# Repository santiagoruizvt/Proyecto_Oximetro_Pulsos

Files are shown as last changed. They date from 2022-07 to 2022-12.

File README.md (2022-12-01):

# **Proyecto_Oximetro_Pulsos**
*Repositorio destinado para el proyecto de la materia Técnicas Digitales 3*

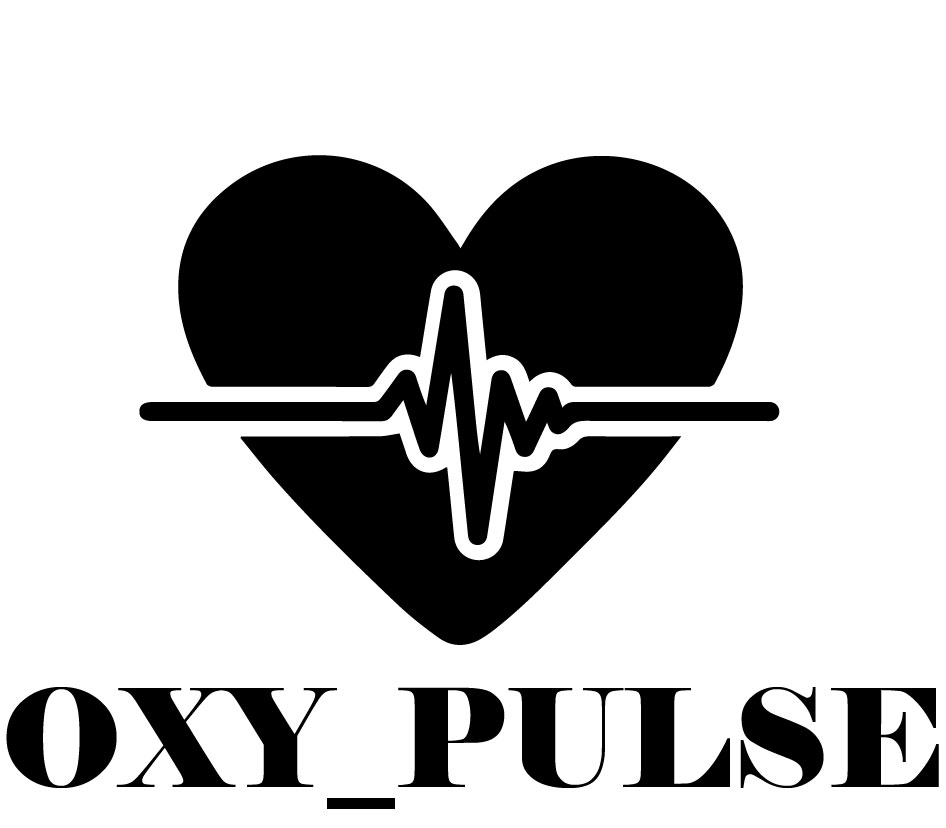
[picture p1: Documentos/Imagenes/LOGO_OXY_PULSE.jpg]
Image text


## Se encuentra disponible en la carpeta "Documentos" el preinforme del proyecto.
## Se encuentra disponible en la carpeta "Documentos" el informe final del proyecto.
## Se agrega el código desarrollado con STM32CubeIDE, con las siguientes configuraciones:

- UART: Se utilizará para la comunicación con el módulo bluetooth HM10.
	- PA2: TX
	- PA3: RX

- SPI: Se utilizará para la comunicación con el módulo R/W de tarjetas Micro SD
	- PB12: CSS
	- PB13: SCK
	- PB14: MISO
	- PB15: MOSI

- I2C1: Se utilizará para la comunicación con el módulo oxímetro MAX30100
	- PB6: SCL
	- PB7: SDA

- I2C2: Se utilizará para la comunicación con la pantalla OLED SSD1306
	- PB10: SCL
	- PB11: SDA

- PULSADOR: Se utilizará para comenzar con la medición.
	- PC14: PULL-UP

# Modelos 3D

## Diseños realizados con Fusion 360 (Autodesk)

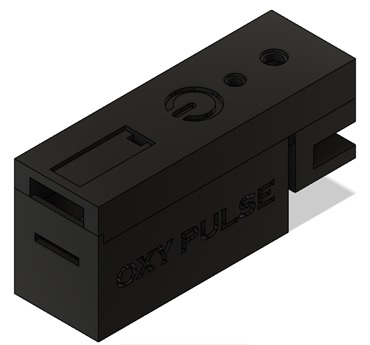
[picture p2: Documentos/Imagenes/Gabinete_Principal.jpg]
Image text


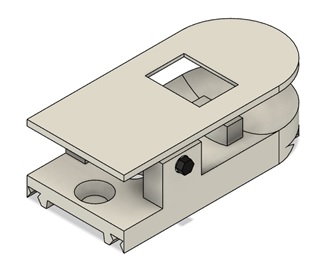
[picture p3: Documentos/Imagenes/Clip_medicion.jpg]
Image text


# PROYECTO FINALIZADO

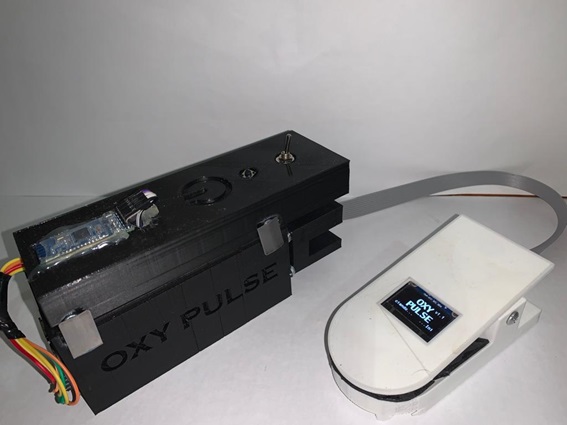
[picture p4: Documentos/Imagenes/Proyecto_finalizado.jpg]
Image text


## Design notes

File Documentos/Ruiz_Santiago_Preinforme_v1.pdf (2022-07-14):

## Oxy_Pulse

Alumno:

- Ruiz Santiago

Descripción funcional del proyecto:

“Oxy_Pulse” es un oxímetro de pulsos y medidor de frecuencia cardíaca, diseñado para ser un dispositivo portátil y de fácil manejo para el usuario.
Es importante conocer los niveles de oxígeno en sangre, ya que si este es bajo las células del organismo pueden tener dificultades para cumplir adecuadamente sus funciones. El oxígeno es el “combustible” del cuerpo y cuando el 02 falta el cuerpo no funciona bien. Los bajos niveles de oxígeno también pueden repercutir sobre el corazón y el cerebro.
Este dispositivo mide los niveles de oxígeno en sangre sin necesidad de entrar en contacto con la misma y los presenta en pantalla para su lectura. El nivel de oxígeno en sangre obtenido se denomina “nivel de saturación de oxígeno” e indica cuánto oxígeno transporta la sangre en relación al máximo que sería capaz de transportar. En circunstancias normales, más del 89% de los glóbulos rojos debería contener oxígeno.
El dispositivo además indica la frecuencia cardíaca del usuario, y envía alertas por bradicardia o taquicardia vía Bluetooth a una aplicación móvil sencilla que el usuario puede descargar en su teléfono.
Por otra parte, cuenta con un módulo para tarjetas SD, donde se irán almacenando datos de lecturas que el usuario luego podrá utilizar a la hora de elaborar un informe médico.

Descripción técnica del proyecto:

- Entradas y salidas del sistema
- Entradas: Sensor MAX30102 y pulsador de PULL-UP.
- Salidas: Módulo Bluetooth HM10, Módulo SD Card R/W, Pantalla OLED SSD1306, leds indicadores.
- Sensores a utilizar
- Sensor oxímetro de pulsos y medidor de frecuencia cardíaca MAX30102 o MAX30100
- Circuitos integrados incluidos en el sistema
- Módulo HM10 para la conexión bluetooth del dispositivo.
- Pantalla OLED SSD1306.
- Módulo SD Card (OKY 3001) o Micro SD
- Tipo de alimentación: el dispositivo contará con baterías de litio tipo 18650 con posibilidad de recargarlas utilizando un módulo de carga TP4056.
- Comunicaciones a efectuar con los distintos módulos:
- I2C1: se utilizará para comunicar el STM32F103 con el módulo oxímetro, utilizando los pines PB7(SDA1) y PB6(SCL1).

- I2C2: se utilizará para comunicar el STM32F103 con la pantalla OLED, utilizando los pines PB11(SDA2) y PB10(SCL2)
- UART: se utilizará para comunicar el STM32F103 con el módulo bluetooth HM10, utilizando los pines PA2(TX2) y PA3(RX2)
- SPI: se utilizará para comunicar el STMF103 con el módulo de
tarjeta | SD, | utilizando | los | pines | PB12(CS), | PB13(CLK),
PB14(MISO), PB15(MOSI).

Planificación de ejecución:

- Tareas necesarias a llevar a cabo para desarrollar el proyecto:
- Testeos de los componentes:
- Prueba de módulo bluetooth HM10: Se realizará una prueba enviando un carácter vía bluetooth para encender y apagar un led.
- Prueba de pantalla OLED SSD1306: Se buscará escribir en pantalla alguna frase e ir mostrando el cambio de alguna variable. Como segunda prueba, se buscará graficar algún símbolo o imagen relacionada con la funcionalidad del proyecto (señal ECG de referencia o un corazón latiendo)
- Prueba del módulo R/W de Tarjetas SD(o Micro SD): Se realizará el conexionado y se buscará escribir la memoria SD, para luego hacer una lectura de esta información en la PC.
- Prueba del módulo MAX30100(o 30102): Se realizará una prueba de la recepción de datos vía I2C para luego procesarlos con el STM32F103.
- Diseño e impresión en 3D de las partes mecánicas del proyecto.
- Redacción de programas para cada módulo

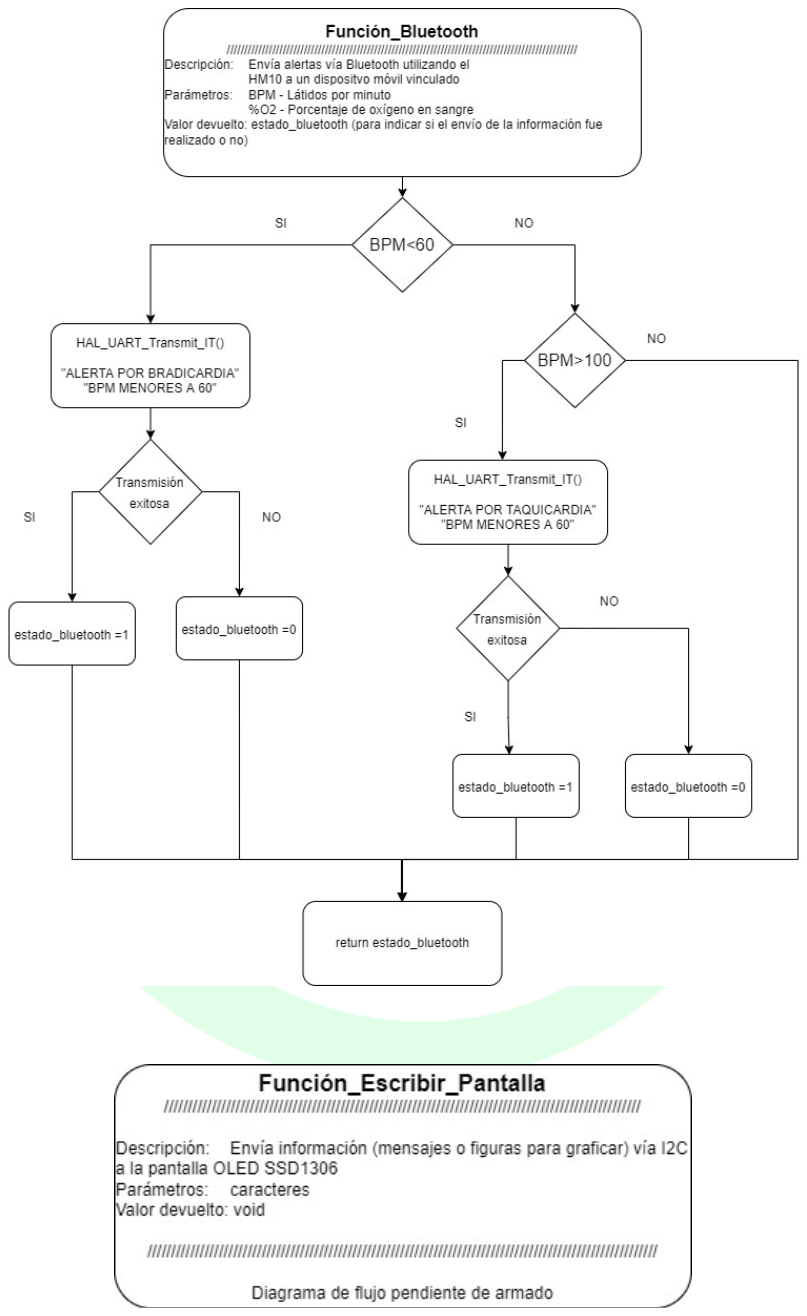
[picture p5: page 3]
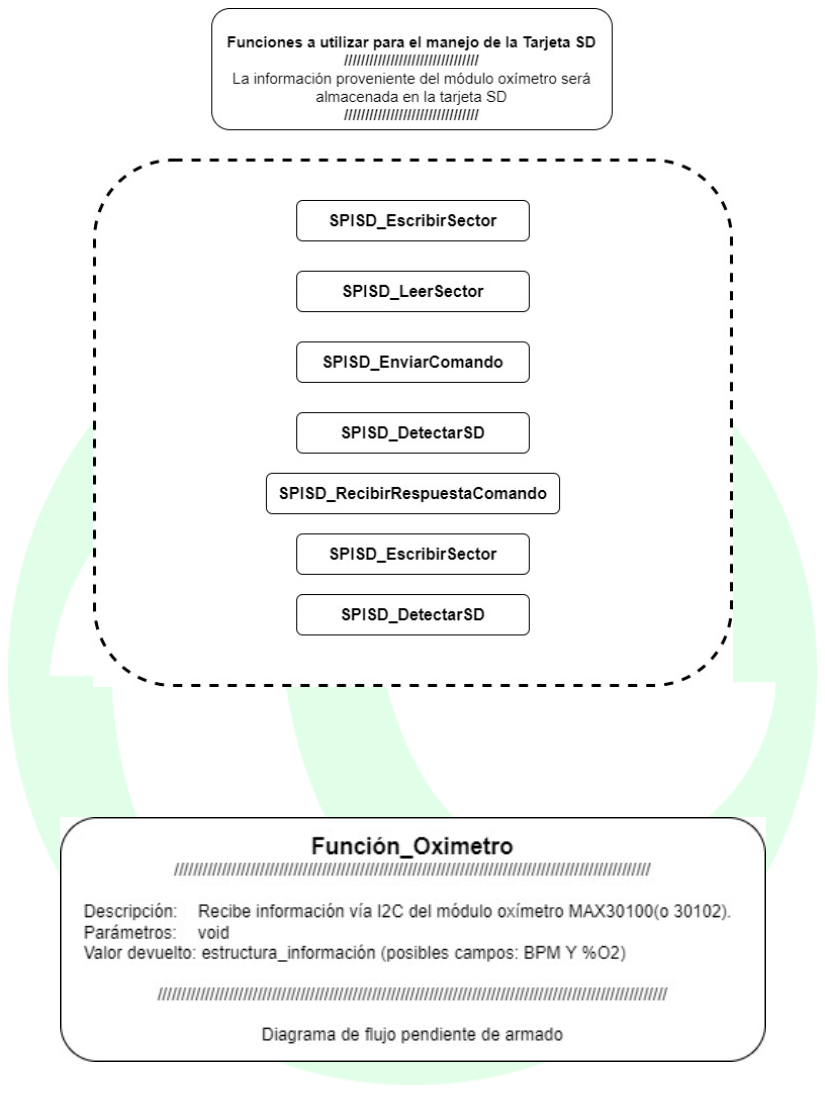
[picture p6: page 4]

- Diseño del programa del sistema

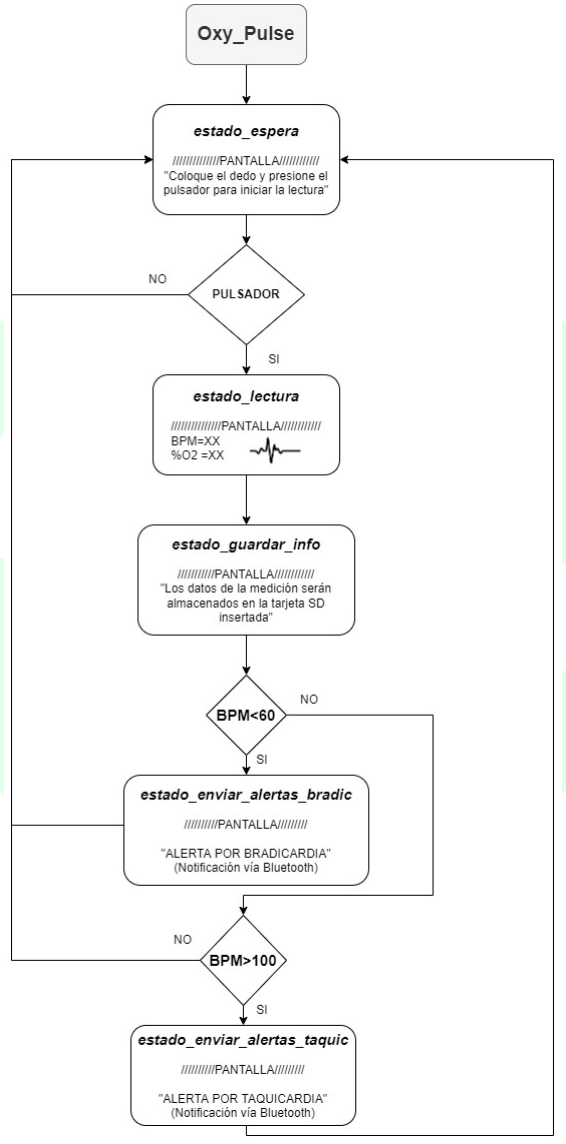
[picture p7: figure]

- Diseño y armado de PCBs: el PCB será incluido en esta sección y será en función del siguiente circuito esquemático:

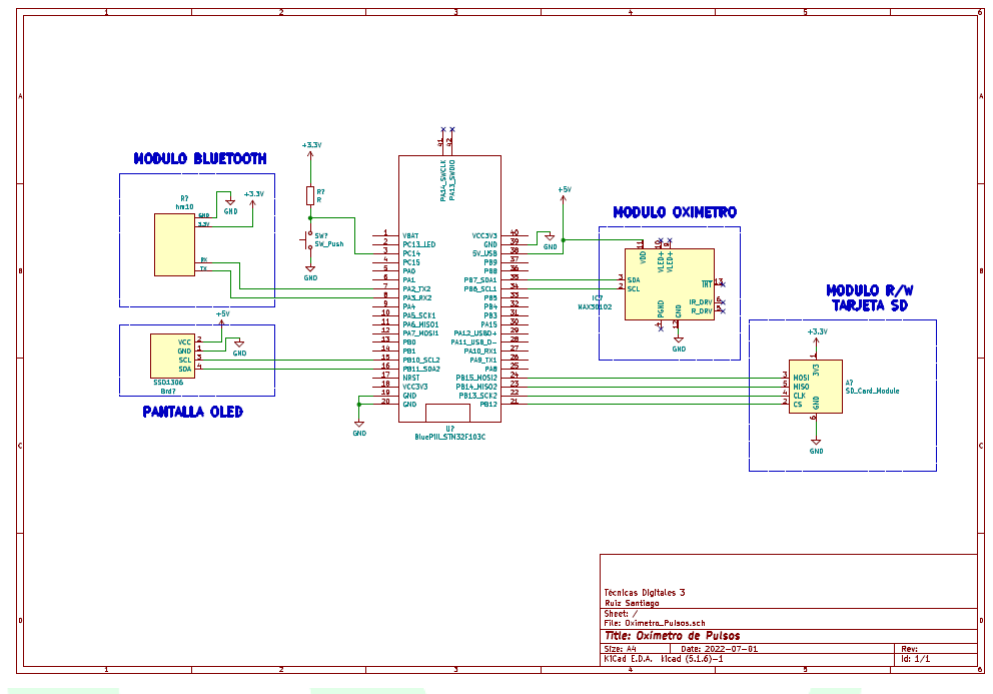
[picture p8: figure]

- Orden de las tareas:
1. Diseño del circuito esquemático
2. Prueba de módulo Bluetooth HM10
3. Prueba de pantalla OLED SSD1306
4. Prueba de módulo de Tarjeta SD
5. Prueba de módulo oxímetro MAX30100/MAX30102
6. Diseño e impresión en 3D de las partes mecánicas
7. Diseño y procesado del PCB
8. Armado y prueba del funcionamiento en conjunto

- Tiempo estimado para cada tarea:
TAREA A REALIZAR | ABRIL | MAYO | JUNIO | JULIO | AGOSTO | SEPTIEMBRE | OCTUBRE | NOVIEMBRE
Propuestas de Proyectos y Elección del definitivo

Elección de sensores y módulos a utilizar

Diseño de Circuito Esquemático

Prueba de módulo Bluetooth

Prueba de pantalla OLED
Prueba de módulo de Tarjeta SD

Prueba del módulo oxímetro

Diseño e impresión 3D de las partes mecánicas

Diseño y Procesado del PCB

Pruebas en conjunto y coordinación

Programación Principal
Corrección de Errores y Ajustes

Presentación

La extensión mínima del documento entregado deberá ser de tres páginas y se debe respetar el formato de este modelo, no solo en el tipo de letra y la tabulación, sino también en el orden y presencia de los títulos incluidos. Téngase en cuenta que conforme más información (tanto de la parte técnica como de la planificación) se entregue, mas fácil será para la cátedra el acotar los proyectos a los tiempos y conocimientos de los cuales se dispone y más efectivo podrá ser el seguimiento que se hará de los mismos, siendo los alumnos los principales beneficiarios.

Universidad Nacional de La Matanza

Técnicas Digitales III

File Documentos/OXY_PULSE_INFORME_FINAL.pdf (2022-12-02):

## UNIVERSIDAD NACIONAL DE LA MATANZA

## Departamento de Ingeniería e Investigaciones Tecnológicas

## Ingeniería en Electrónica

# Técnicas digitales III

# OXY_PULSE

Alumno: | Santiago Ruiz
Profesores: | Lic. Carlos Maidana
| Ing. Guillermo Buranits
| Ing. Edgardo Alberto Gho

2022

## ÍNDICE

UNLaM | Ingeniería Electrónica | Técnicas digitales III
RUIZ | 1

## 1 Descripción general

El control de la frecuencia cardíaca y del nivel de oxigenación en sangre es un hábito saludable que las personas, incluso si no son atletas, deberían practicar. Esto ayuda a controlar el estado físico e inclusive a detectar problemas de salud. Existen diversas formas de conocer la frecuencia del pulso cardíaco, detectándolo en alguna zona sensible del cuerpo como las muñecas o de lado del cuello. La más conocida consiste en contar los latidos que uno encuentra tocando estas zonas durante 60 segundos.

Como solución tecnológica a esta necesidad, se presenta “OXY_PULSE”. Se trata de un oxímetro de pulsos diseñado para ser portátil y de fácil manejo para el usuario. Con la ayuda de este dispositivo, el usuario podrá realizar una medición de su frecuencia cardíaca y de la saturación de oxígeno en sangre, sin tener que extraer una muestra de sangre. Estos valores podrán leerse en pantalla de forma rápida y en unos pocos segundos, para tener así una noción de sus latidos por minuto y oxigenación. Para le medición, solo se necesita colocar el dedo en el sensor e iniciar la lectura accionando un pulsador.

Adicionalmente, el dispositivo cuenta con conectividad Bluetooth, para poder conectarse y enviar información a un dispositivo móvil. Además, enviará alertas en caso de que las lecturas de frecuencia cardíaca no estén dentro de un rango de valores normales para un adulto.

Existe además la posibilidad de conectar una tarjeta SD, donde se irán guardando valores de latidos por minuto (BPM) o saturación de oxígeno en sangre (SPO2) por cada lectura que se haga, lo cual podría ser de utilidad a la hora de elaborar un informe médico.

En resumen, se desarrolla un dispositivo para utilizar en el hogar, sin tener conocimientos técnicos ni médicos, que pueda entregar al usuario una noción rápida de sus niveles de oxigenación y frecuencia cardíaca de manera sencilla.

Figura 1 - Logotipo OXY_PULSE

## 2 Introducción teórica

El monitoreo de parámetros como la frecuencia cardíaca y la saturación de oxígeno es hoy en día una necesidad a nivel mundial para el cuidado médico de pacientes. Y si se toma en cuenta lo sucedido con la pandemia del COVID-19, el control de estos parámetros se enfatizó debido a las características y consecuencias de la enfermedad. Estos parámetros proporcionan información acerca del paciente, aun cuando este no puede expresarlo por sus propios medios y cualquier desviación de los valores considerados normales de estos signos vitales puede significar un riesgo en la salud del paciente. Se consideran signos vitales al ritmo cardíaco, la presión arterial, la temperatura corporal y la frecuencia respiratoria. Y desde la aparición del primer oxímetro de pulsos en 1975 se considera a la saturación de oxígeno como el quinto signo vital.
Para entender el funcionamiento de un oxímetro, primero es necesario desarrollar algunos conceptos teóricos. La sangre es tejido vivo formado por líquidos y sólidos. La parte líquida, llamada plasma, contiene agua, sales y proteínas. Más de la mitad del cuerpo humano es plasma. Mientras que la parte sólida de la sangre contiene glóbulos rojos, glóbulos blancos y plaquetas. Dentro del plasma, la hemoglobina es la proteína principal que transporta el oxígeno en la sangre, y cambia de color cuando se une al oxígeno. La hemoglobina consiste en proteínas globulares, presentes en los hematíes en altas concentraciones, que fijan oxígeno en los pulmones y lo transportan por la sangre hacia los tejidos y células que rodean el lecho capilar del sistema vascular. Al volver a los pulmones, desde la red de capilares, la hemoglobina actúa como transportador de CO2 y de protones. Considerando este cambio de color mencionado, un oxímetro podrá detectar con el uso de sensores los cambios de color en la sangre debido al movimiento de hemoglobina unida al oxígeno, obteniendo una cantidad porcentual de moléculas de hemoglobina conocida como saturación de oxígeno en sangre (SPO2). En forma resumida, la principal función de la hemoglobina es el transporte de oxígeno (O2) de los pulmones donde la presión es elevada hacia los tejidos donde es baja.

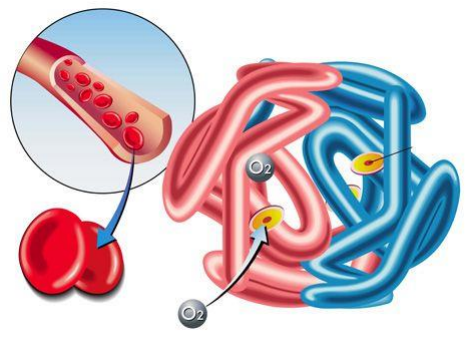
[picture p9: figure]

Figura 2 – Molécula de Hemoglobina

A partir de estos conceptos es que surge la oximetría, definida en términos generales como la medición óptica de la saturación de oxihemoglobina en la sangre. En particular será de interés la oximetría de pulsos.
Un instrumento que sería capaz de detectar los cambios de color mencionados es un espectrofotómetro, el cual tiene la capacidad de detectar con precisión la reflectancia del color o la transmisión de luz para el análisis cuantitativo. Cada muestra física tiene su propia reflectancia (cantidad de luz que refleja) y transmitancia (absorción de luz). Desarrollando un poco más, un espectrofotómetro mide la intensidad de la luz transmitida a través de una sustancia a una determinada longitud de onda. La fracción de luz absorbida a una cierta longitud de onda está dada por la absortividad. El espectrofotómetro posee un fotodetector, el cual convierte la intensidad de luz en corriente eléctrica. A una intensidad de luz dada transmitida a través de una sustancia se produce una corriente eléctrica proporcional a dicha intensidad. Si se mide la intensidad de luz incidente sobre un material (Io) y la intensidad de luz transmitida a través del mismo material (I) se determina la transmitancia, definida por la siguiente ecuación:

T =

I
Io

(1)

Dado que cada molécula absorbe una proporción igual de luz, la absorbancia de la luz a través de la sustancia esta linealmente relacionada con la concentración de la misma. La absorbancia se obtiene a partir de la transmitancia medida según la ecuación 2:

At = − ln(T) = −ln (

I
Io
) | (2)

Un oxímetro de pulsos irradia luz de dos longitudes de onda a través de una capa de tejido y mide la señal de la luz transmitida. El dispositivo apoya su funcionamiento en dos leyes principales, la ley de Lambert y la ley de Beer. La ley de Lambert establece que la potencia de una radiación electromagnética monocromática que incide perpendicularmente en una superficie decrece exponencialmente con el espesor del medio atravesado. La radiación absorbida por el medio se representa con la absorbancia, definida por la ecuación 3, donde b es espesor del medio y k1 una constante de proporcionalidad del medio.

Ai = (

k1
2,3
)b | (3)

Se observa que la absorbancia es directamente proporcional al espesor del medio atravesado. Por otra parte, la Ley de Beer establece que la potencia de una radiación electromagnética monocromática que incide perpendicularmente sobre una muestra decrece exponencialmente con la concentración de la muestra, siguiendo la ecuación 4:

Ab = (

k2
2,3
) c | (4)

Donde c es la concentración de la muestra, k2 una constante de proporcionalidad y Ab la absorbancia.
Combinando las leyes mencionadas anteriormente, se obtiene la Ley de Lambert-Beer que describe la atenuación de la luz que viaja a través de un medio uniforme que contiene una sustancia absorbente. La intensidad I de la luz que viaja a través del medio decrece exponencialmente con las distancias y está definida por la ecuación 5, donde ε(λ) es el coeficiente de extinción de la sustancia absorbente, λ es la longitud de onda, c es la concentración de la sustancia absorbente que es constante en el medio, y d es la longitud del camino óptico a través del medio.

I = Ioe

−ε(λ)cd
(5)

En la Figura 3, se puede observar un diagrama de absorción de un haz que atraviesa un recipiente de tamaño L:

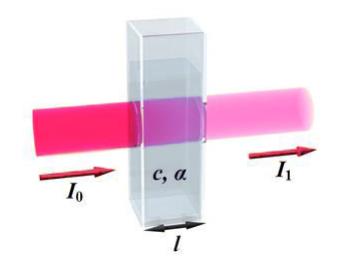
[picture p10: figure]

Figura 3 – Representación de la Ley de Lambert-Beer

Las propiedades de esta ley son válidas incluso si hay más de una sustancia absorbente en el medio. Cada sustancia contribuye con su parte a la absorbancia total dando como resultado que la misma es la suma de las n-ésimas absorbancias presentes en el medio. Volviendo al instrumento de interés para el trabajo, un oxímetro de pulsos irradia luz de dos longitudes de onda a través de una capa de tejido y mide la señal de la luz transmitida.
En primer lugar, el oxímetro mide cuanta cantidad de luz alcanza al fotodetector y en función de esto determina cuanta luz ha sido absorbida. La hemoglobina absorbe luz y la cantidad de luz absorbida es proporcional a la concentración de hemoglobina. Por eso a mayor concentración de hemoglobina en la zona que se está observando, mayor luz será absorbida.

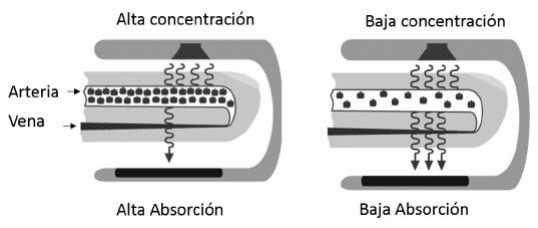
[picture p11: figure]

Figura 4 – Aplicación de la Ley de Beer

En segundo lugar, la cantidad de luz absorbida es proporcional a la longitud del camino de luz. Esto describa una posible situación donde en dos dedos humanos diferentes pueden existir arterias que tienen la misma concentración de hemoglobina por unidad de área, pero estas arterias pueden ser de diferentes espesores. En la de mayor espesor, la luz emitida desde la fuente debe recorrer un camino de mayor longitud que en la arteria más pequeña, aunque la concentración de hemoglobina sea la misma en ambas arterias. En la arteria de mayor espesor, el medio absorbe mayor cantidad de luz.

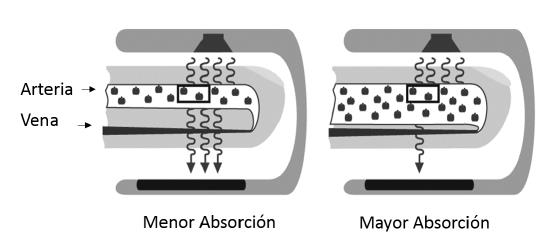
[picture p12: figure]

Figura 5 – Aplicación de la Ley de Lambert

Como última consideración, es importante mencionar que la oxihemoglobina absorbe mayor cantidad de radiación infrarroja y la desoxihemoglobina absorbe mayor cantidad de radiación roja. Es por esto que el oxímetro utiliza dos haces de luz de diferentes longitudes de onda para analizar la hemoglobina: un haz es la luz roja con una longitud de onda de 650nm aproximadamente, mientras que el otro haz es luz infrarroja con una longitud de 950nm. Graficando la absorbancia de la oxihemoglobina y la desoxihemoglobina, se obtiene una gráfica como la de la figura 6:

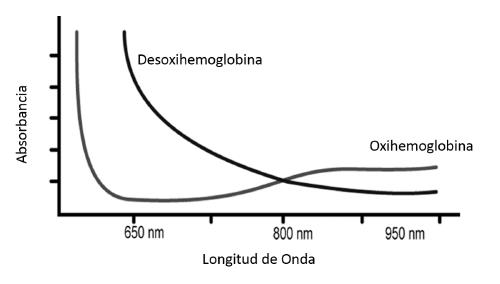
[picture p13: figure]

Figura 6 – Absorbancia en función de la longitud de onda

De la figura 6 se entiende que para valores infrarrojos (950nm) la absorbancia de la oxihemoglobina es mayor que para valores de longitudes de onda menores. De forma similar, pero observando la curva de desoxihemoglobina se observa que absorbe mayor luz de longitud de onda roja (650nm) que infrarroja.
El oxímetro de pulsos opera determinando la saturación de oxígeno al comparar cuanta luz roja e infrarroja es absorbida por la sangre. Dependiendo de las cantidades de oxihemoglobina y desoxihemoglobina, la relación de luz roja absorbida se compara con la relación de luz infrarroja absorbida.
Se define como onda fotopletismográfica al cambio de volumen del flujo sanguíneo. En las extremidades, como un dedo, esta onda se ve afectada por diversos factores como ruido ambiental, anormalidades en la sangre, movimientos no controlados del cuerpo, etc. Y además, no solo está presente la sangre arterial en el dedo, sino que existen sustancias, como los tejidos, que pueden interferir en la medición. La solución para este inconveniente es la detección de una absorbancia pulsante por parte de la sangre arterial, mientras que el resto de los tejidos no cuentan con esta característica. Por ende, cualquier absorbancia variable en el tiempo se debe a sangre arterial. Se puede decir entonces, que la señal que llega al oxímetro de pulsos es una combinación de una absorbancia variante debido a la sangre arterial y una absorbancia constante debida a la piel y otros tejidos, como se aprecia en la figura 7.

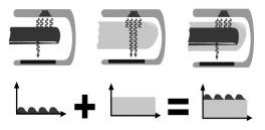
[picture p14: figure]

Figura 7 – Combinación de absorbancias de la sangre y otros tejidos

## 3 Descripción técnica del proyecto

El prototipo consta de dos partes principales. El gabinete principal, donde se aloja el microcontrolador, y un clip externo donde se deberá colocar el dedo para la medición. El diseño de estas piezas fue realizado en el software Autodesk Fusion 360, y las mismas fueron impresas en 3D en PLA.

## 3.1 Mecánica

El prototipo no posee partes móviles exceptuando el clip donde el usuario coloca el dedo. El mismo fue pensado para que, con el uso de un resorte, pueda volver a la posición original luego de ser abierto.

## 3.1.1 Diagrama en bloques

En el siguiente diagrama, se muestran las partes del dispositivo mencionadas anteriormente. La unión entre ellas será un cable plano que conectará el microcontrolador con la pantalla y el módulo oxímetro.

Figura 8 – Diagrama en bloques de la parte mecánica

## 3.1.2 Funcionamiento de cada bloque

El primer bloque es el gabinete principal. Su función es la de la contener la placa principal del prototipo, así como también algunos módulos como el bluetooth o la tarjeta SD. En ella se aloja el microcontrolador. Fue diseñada con el software mencionado anteriormente, y en sus laterales se puede observar el nombre “OXY_PULSE” y un logotipo del producto.
En segundo lugar, se tiene el clip o broche para medición. En él se encuentra una pequeña pantalla OLED, donde el usuario podrá ir leyendo los valores que se están obteniendo, y el módulo oxímetro donde deberá apoyar el dedo a la hora de realizar la medición.

## 3.1.3 Fotos

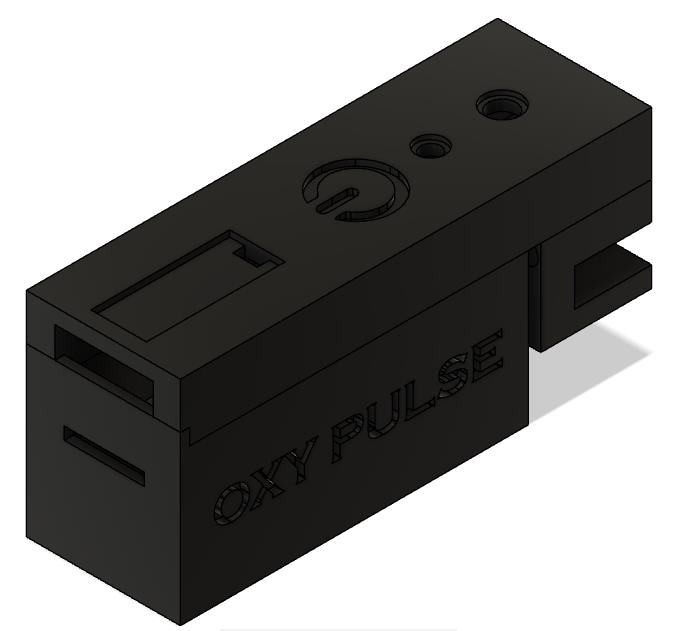
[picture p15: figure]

Figura 9 – Gabinete principal

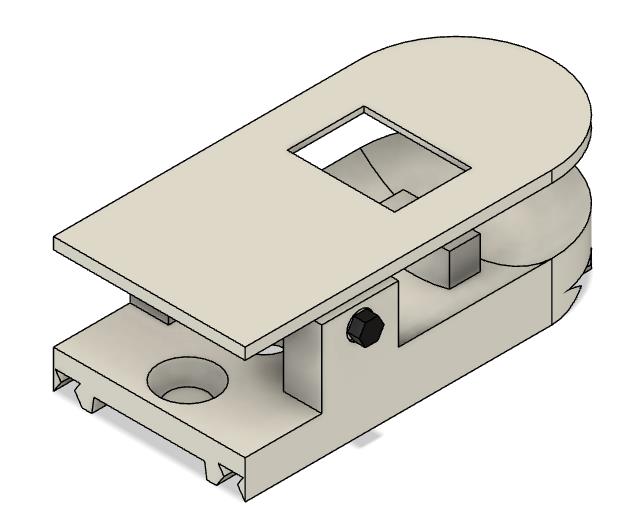
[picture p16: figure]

Figura 10 – Clip para medición

## 3.2 Hardware

En cuanto al hardware, la electrónica del proyecto quedará distribuida en las dos partes mencionadas anteriormente. En el gabinete principal se encontrará la placa con el microcontrolador, el módulo Bluetooth y el módulo para tarjetas SD. Además, se tiene un conector IDC, de donde saldrá la conexión hacia el clip de medición. En este último se encontrará la pantalla OLED y el módulo oxímetro.

## 3.2.1 Diagrama en bloques

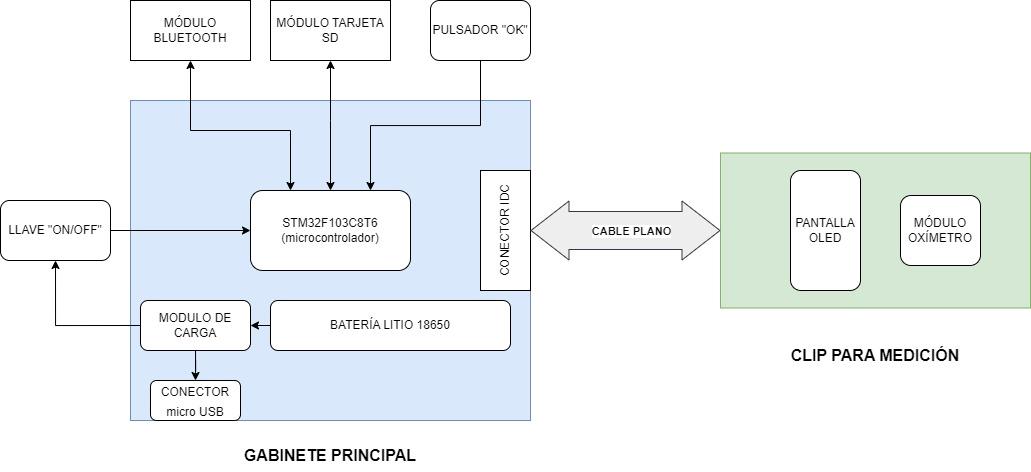
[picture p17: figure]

Figura 11 – Diagrama en bloques de OXY_PULSE

El diagrama presentado se encuentra dividido en dos grandes bloques, los cuales coinciden con las dos partes mecánicas mencionadas en la sección anterior. A continuación, se irán detallando cada una de sus partes.

## 3.2.2 Esquemático

MICROCONTROLADOR – STM32F103C8T6
Se trata de un Cortex M3 de 32 bits, de arquitectura ARM. Permite una frecuencia máxima de operación de 72MHz, con una memoria Flash de 64/128KB, periféricos como I2C, DMA, UART, SPI, CAN, USB, entre otros. Cuenta con 5 timers y 37 pines GPIO. Será el encargado de coordinar las tareas de OXY_PULSE, interactuando con los módulos que se detallarán a continuación.

MÓDULO OXIMETRO
El módulo seleccionado es el MAX30100. Para la selección de este se enfocó la búsqueda en un dispositivo integrado capaz de realizar medición de latidos por minuto y saturación de oxígeno en sangre, tareas principales del dispositivo. El dispositivo consiste en un pulsioxímetro integrado, compuesto por dos LEDS, uno rojo y uno infrarrojo, un fotodetector y un sistema de procesamiento digital de señales para la correcta detección de valores. Sus principales aplicaciones son el uso en accesorios como smartwatch o pulseras de uso deportivo para el monitoreo del pulso cardíaco, y en dispositivos de electromedicina sencillos.
Respecto a la alimentación, el MAX30100 debe ser alimentado desde 1,8V a 3,3v. Pero el módulo utilizado cuenta con un pequeño regulador de 3,3v, por lo que se podría alimentar el módulo con 5V.

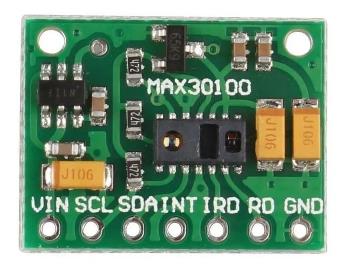
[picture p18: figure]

Figura 12 – MAX30100

Lo interesante de este módulo es que cuenta con interfaz I2C para la comunicación con un microcontrolador. En la hoja de datos del MAX30100, se especifica que para el correcto funcionamiento del bus I2C, se deben colocar resistencias de PULL-UP de 4700Ω.

Figura 13 – BUS I2C MAX30100

En el caso del módulo utilizado, contaba con 3 resistencias de PULL-UP de montaje superficial conectadas de forma errónea, lo cual es un error frecuente en estos módulos. Por este motivo, dichas resistencias fueron quitadas del módulo y colocadas en forma externa en la placa principal.

MÓDULO BLUETOOTH
Para la conectividad Bluetooth, el módulo seleccionado es el HM10. Este módulo cuenta con una versión Bluetooth 4.0 BLE. Las siglas BLE, Bluetooth Low Energy, hacen referencia a una tecnología inalámbrica diseñada para que el consumo de energía sea mucho menor que un bluetooth convencional, aproximadamente un 10% de este. La característica principal es que un dispositivo BLE actúe la mayor parte del tiempo en modo STAND-BY, y sea solo activado para realizar comunicaciones que duran milisegundos. Es por esto, que es una tecnología ideal para dispositivos móviles, smartwatch, etc.
Cuenta con interfaz UART, por lo que con una conexión de 2 hilos (Rx-Tx) de tipo asincrónica puede interactuar con un microcontrolador para transmitir o recibir información.

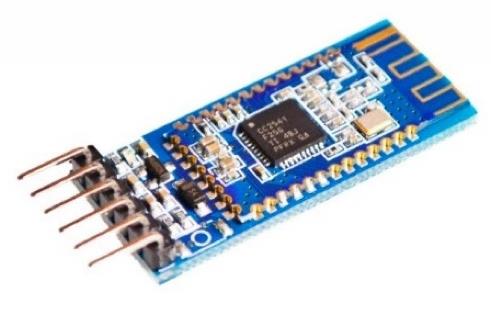
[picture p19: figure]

Figura 14 – BUS I2C MAX30100

PANTALLA OLED
Para la presentación de la información obtenida, se utiliza un módulo Display OLED SSD1306. Posee un panel de 128x64 pixeles y existen versiones multicolor, azules o blancas. Esta última es la utilizada en OXY_PULSE. Cuenta con interfaz I2C para la conexión con un microcontrolador y su alimentación es compatible con lógica de 3,3V.

Figura 15 – Pantalla OLED SSD1306

MODULO TARJETA microSD
Para almacenar información relevante del usuario en una memoria microSD, se utiliza un módulo lector de microSD, para acceder a la memoria en modo SPI. El módulo incluye un “Level-Translator”, para convertir los niveles lógicos de 5v a 3,3V. La comunicación con el microcontrolador es vía SPI, por lo que se tienen 4 hilos (MISO, MOSI, CS, SCK), además de la alimentación.

Figura 16 – Módulo memoria microSD

MODULO DE ALIMENTACIÓN Y CARGA
Para energizar el dispositivo, se utiliza una batería de litio recargable 18650, de la marca UltraFire. La misma proporciona una tensión de 3,7V y una capacidad de 5800mAh. Esta será la encargada de alimentar todos los módulos del dispositivo con lógica de 3,3V. Para la carga de la batería, se utiliza un módulo TP4056 con protección. La ventaja en el uso de este módulo es que cuenta con unos transistores MOSFETs que desconectan la batería del circuito cuando la misma necesita recargarse. Además, posee un conector microUSB para realizar la carga de la batería. Mientras se realiza la carga, el módulo enciende un LED rojo, y cuando la batería llega a plena carga se enciende un LED azul. El diagrama del conexionado es el siguiente:

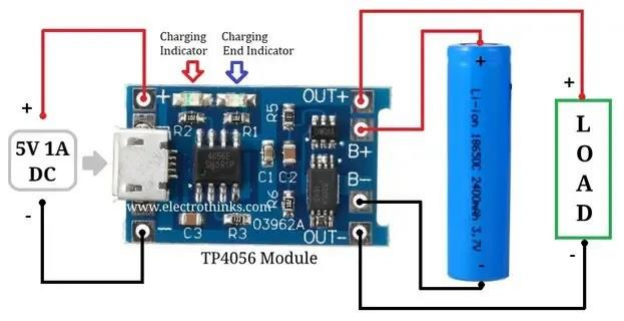
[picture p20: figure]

Figura 17 – Módulo TP4056

LLAVE “ON-OFF” y PULSADOR “OK”
Para el encendido y apagado del dispositivo, se utiliza una mini llave de dos posiciones, que soporta hasta 3A, la cual está en serie con la batería y la bornera principal de la placa.
Por otra parte, el dispositivo cuenta con un pulsador con el cual el usuario podrá iniciar la medición con el oxímetro, así como también detenerla pulsando nuevamente.

CONECTOR IDC
La conexión entre el gabinete principal y el clip para medición es a partir de un conector IDC con latch, el cual permite una conexión hermética sumamente fiable, evitando posibles falsos contactos.

## 3.2.3 Circuito impreso

En el prototipo se cuenta con dos circuitos impresos, diseñados con el software libre KiCad. El primero de ellos y principal, es la placa donde se encuentra el microcontrolador. En ella, se encuentran las conexiones hacia los diferentes módulos mencionados en la sección anterior, así como también resistencias de PULL-UP para los usos ya especificados. El segundo, se trata de una pequeña placa para colocar el conector IDC y darle rigidez mecánica.

## 3.2.4 Fotos

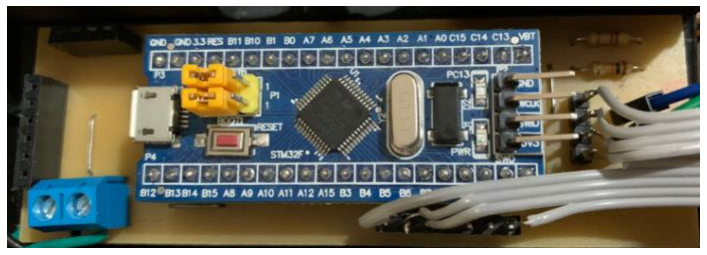
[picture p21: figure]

Figura 18 – PCB principal lado componentes

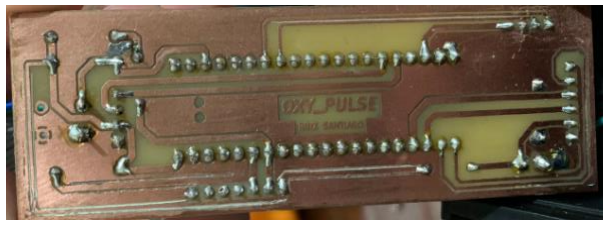
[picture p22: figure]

Figura 19 – PCB principal lado cobre

Figura 20 – PCB para conector IDC

## 3.3 Software

El software de OXY_PULSE fue desarrollado utilizando una herramienta de desarrollo de STMicroelectronics conocida como STM32CubeIDE. Esta basada en el marco Eclipse y la de cadena de herramientas GCC para el desarrollo y GCB para la depuración. Desde el propio entorno, se puede realizar la configuración de la placa de desarrollo utilizando la interfaz del archivo “.ioc”.
El contenido del proyecto fue organizado en archivos, resolviendo cada módulo por separado e incluyendo dichos archivos en el programa principal. Todo el contenido relacionado podrá encontrarse en el repositorio de Github correspondiente a OXY_PULSE. Se puede acceder al mismo siguiendo este link:

https://github.com/santiagoruizvt/Proyecto_Oximetro_Pulsos

## 3.3.1 Enumeración de rutinas

Las rutinas enumeradas a continuación se irán enumerando en grupos según la tarea que cumpla cada una de ellas.

MAX30100.c

Rutina “MAX30100_Init”

//*************************************************************
//Función: | MAX30100_Init
//Descripción: | Inicialización del módulo MAX30100
//Parámetros: | void
//Valor devuelto: | void
//*************************************************************

Subrutina “MAX30100_I2C_Write”

//*************************************************************
//Función: | MAX30100_I2C_Write
//Descripción: | Escritura de un buffer a traves del bus I2C
//Parámetros: | uint8_t dirección del dispositivo
// | uint8_t registro a escribir
// | uint8_t data a escribir
//Valor devuelto: | void
//*************************************************************

Rutina “Actualizar_Resultados”

Subrutina “Resetea_Resultados”

//*************************************************************
//Función: | Resetea_Resultados
//Descripción: | Resetea la estructura result para comenzar
// | o realizar una nueva lectura
//Parámetros: | pulseoxymeter_t* puntero a estructura result
//Valor devuelto: | void
//*************************************************************
Subrutina “Lectura_FIFO”

//*************************************************************
//Función: | Lectura_FIFO
//Descripción: | Lectura de los valores de IR y REDLED desde
// | el registro FIFO del MAX30100
//Parámetros: | FIFO_t* puntero a estructura FIFO
//Valor devuelto: | void
//*************************************************************
Subrutina_2 “MAX30100_I2C_Read”

//*************************************************************
//Función: | MAX30100_I2C_Read
//Descripción: | Lectura de un buffer a traves del bus I2C
//Parámetros: | uint8_t dirección del dispositivo
// | uint8_t registro a escribir
// | uint8_t data a escribir
//Valor devuelto: | void
//*************************************************************

Subrutina “Filtrado_DC”

//*************************************************************
//Función: | Filtrado_DC
//Descripción: | Filtrado para quitar la señal continua
// | presente en los valores leídos
//Parámetros: | float datos del FIFO
// | float* valor previo w
// | float* dato filtrado
//Valor devuelto: | void
//*************************************************************
Subrutina “Filtro de Mediana”

//*************************************************************
//Función: | Mean_Median_Filter
//Descripción: | Filtro de mediana para reducir el ruido y
// | limpiar la señal
//Parámetros: | float datos de la salida del Filtrado_DC
// | meanDiffFilter_t* puntero a estructura
// | float* puntero a dato filtrado resultante
//Valor devuelto: | void
//*************************************************************

Subrutina “Filtro Pasabajos Butterworth”

//*************************************************************
//Función: | Filtro_PasabajosButterworth
//Descripción: | Filtro pasabajos butterworth implementado
// | con una ecuación en diferencia
//Parámetros: | float datos de la salida del Median_Filter
// | butterworthFilter_t* puntero a estructura
// | float* puntero a dato filtrado resultante
//Valor devuelto: | void
//*************************************************************
Subrutina “detectPulse”

//*************************************************************
//Función: | detectPulse
//Descripción: | Máquina de estados para la detección del pulso
//Parámetros: | float datos de la salida del LPF
//Valor devuelto: | bool
//*************************************************************
Subrutina “Balance_Intensidades”

//*************************************************************
//Función: | Balance_Intensidades
//Descripción: | Corrección de las intensidades de los LEDS
// | para evitar la saturación de la lectura
//Parámetros: | float datos del led rojo
// | float datos del led IR
//Valor devuelto: | void
//*************************************************************
Subrutina “MAX30100_I2C_FIFO_Read”

//*************************************************************
//Función: | MAX30100_I2C_FIFO_Read
//Descripción: | Lectura del FIFO del MAX30100, se leen 2 bytes
// | por cada LED
//Parámetros: | void
//Valor devuelto: | void
//*************************************************************
Subrutina “MAX30100_I2C_Reset_FIFO”

//*************************************************************
//Función: | MAX30100_I2C_Reset_FIFO
//Descripción: | Reseteo el registro FIFO
//Parámetros: | void
//Valor devuelto: | void
//*************************************************************

SSD1306.c

Rutina “SSD1306_Init”

//*************************************************************
//Función: | SSD1306_Init
//Descripción: | Incialización de la pantalla OLED
//Parámetros: | void
//Valor devuelto: | uint8_t OK
//*************************************************************
Rutina “SSD1306_GotoXY”

//*************************************************************
//Función: | SSD1306_GotoXY
//Descripción: | Setea las coordenadas XY para escribir
// | en pantalla
//Parámetros: | uint16_t x
// | uint16_t y
//Valor devuelto: | void
//*************************************************************
Rutina “SSD1306_Puts”

//*************************************************************
//Función: | SSD1306_Puts
//Descripción: | Escritura en pantalla carácter por
// | caracter
//Parámetros: | char* string que se desea escribir
// | FontDef_t* tipo de fuente(formato)
// | SSD1306_COLOR_t color de escritura en
// | caso de pantalla multicolor
//Valor devuelto: | char si devuelve “0” OK
//*************************************************************
Rutina “SSD1306_UpdateScreen”

//*************************************************************
//Función: | SSD1306_UpdateScreen
//Descripción: | Actualización de la pantalla con la
// | transmisión por bus I2C de un buffer
// | con la nueva información a mostrar
//Parámetros: | void
//Valor devuelto: | void
//*************************************************************
Rutina “SSD1306_ScrollRight”

//*************************************************************
//Función: | SSD1306_ScrollRight
//Descripción: | Mensaje en movimiento en pantalla
//Parámetros: | uint8_t desde donde arranco
// | uint8_t donde termino
//Valor devuelto: | void
//*************************************************************

Rutina “SSD1306_Stopscroll”

//*************************************************************
//Función: | SSD1306_Stopscroll
//Descripción: | Detiene el movimiento del mensaje
//Parámetros: | void
//Valor devuelto: | void
//*************************************************************
Rutina “SSD1306_Clear”

//*************************************************************
//Función: | SSD1306_Clear
//Descripción: | Limpia la pantalla
//Parámetros: | void
//Valor devuelto: | void
//*************************************************************
Rutina “SSD1306_DrawPixel”

//*************************************************************
//Función: | SSD1306_DrawPixel
//Descripción: | Carga en el buffer la información de que
// | pixel se debe encender y su color
//Parámetros: | uint16_t coordenada X
// | uint16_t coordenada Y
// | SSD1306_COLOR_t color pixel
//Valor devuelto: | void
//*************************************************************
Rutina “SSD1306_DrawBitmap”

//*************************************************************
//Función: | SSD1306_DrawBitmap
//Descripción: | Dibuja en pantalla una imagen mapeada
// | bit a bit
//Parámetros: | uint16_t coordenada X
// | uint16_t coordenada Y
// | const unsigned char* imagen mapeada bit por bit
// | uint16_t ancho de la imagen
// | uint16_t alto de la imagen
// | uint16_t color de cada pixel
//Valor devuelto: | void
//*************************************************************

Main.c

Rutina “HAL_IncTick”

//*************************************************************
//Función: | HAL_IncTick
//Descripción: | Manejo del Systick para demoras en ms
//Parámetros: | void
//Valor devuelto: | void
//*************************************************************

Rutina “HAL_GPIO_EXTI_Callback”

//*************************************************************
//Función: | HAL_GPIO_EXTI_Callback
//Descripción: | Manejo de la interrucpción externa
//Parámetros: | uint16_t GPIO_Pin
//Valor devuelto: | void
//*************************************************************

## 3.3.2 Descripción del funcionamiento de cada rutina

Diagrama de flujo principal:

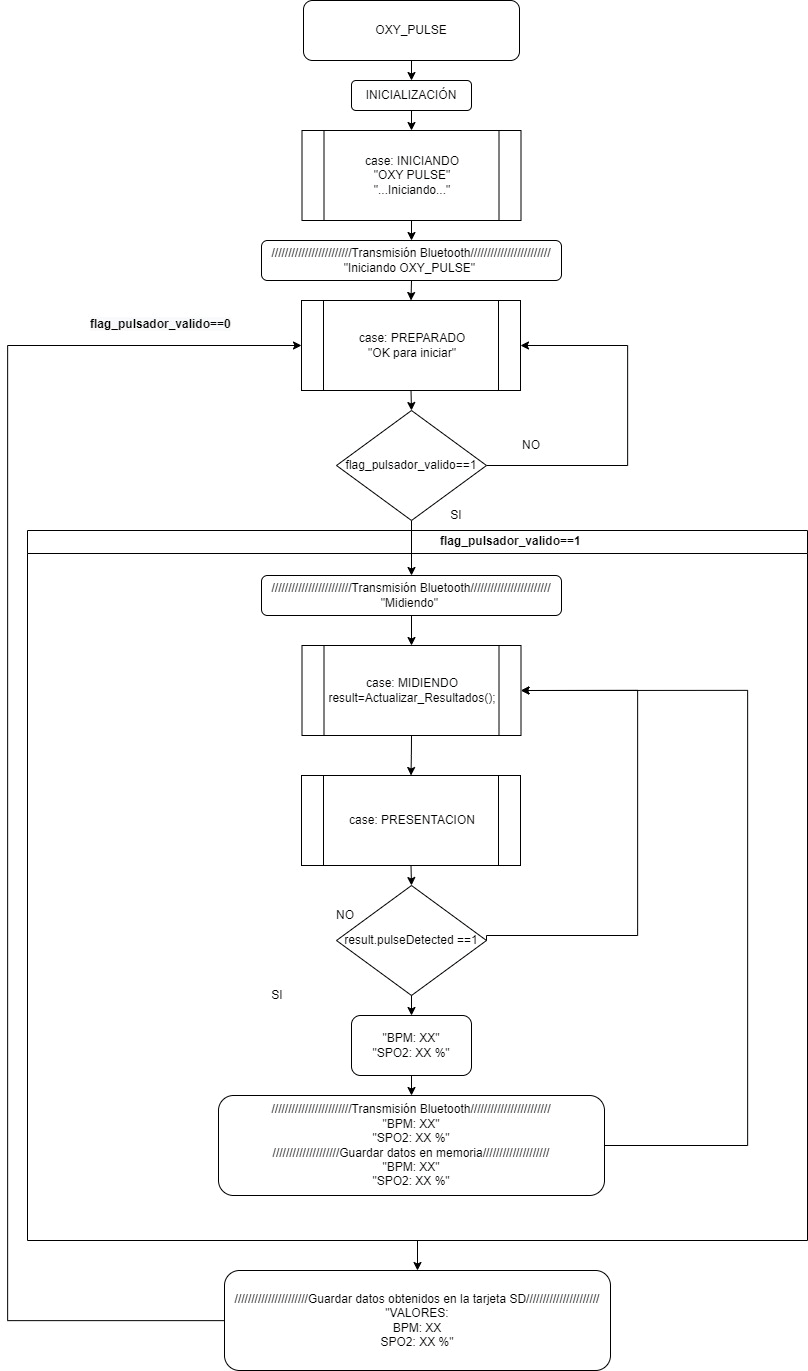
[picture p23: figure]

Figura 21 – Diagrama de flujo principal

Para la detección del pulso, se utilizó una máquina de estados que puede explicarse con la gráfica de la figura 22. En la misma se puede observar una señal muy similar a la de un electrocardiograma, la cual es atravesada por un umbral o “threshold” mínimo en línea punteada. Siguiendo la señal, se llega a su pico y luego comienza a decrecer. En el momento en el cual comienza el descenso en los valores, se guarda un valor de tiempo. En el próximo pico se procede de igual forma, y una vez que se tienen dos muestras de tiempo puede medirse cuanto tiempo pasó entre ellas. De esta forma, pueden calcularse los latidos por minuto de la siguiente manera:

BPM:

60000
Muestra actual − Muestra previa

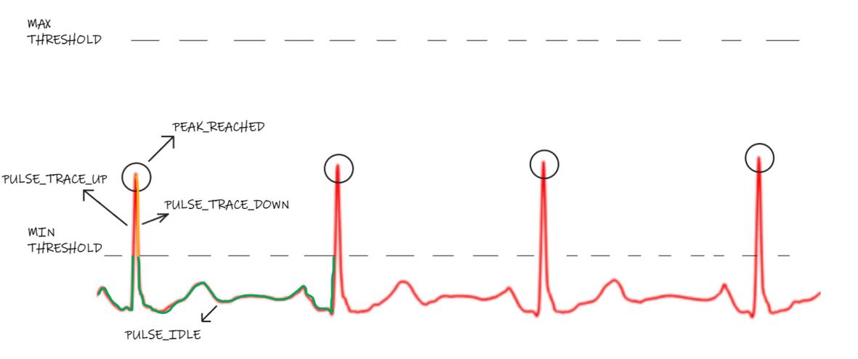
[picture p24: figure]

Figura 22 – Ilustración de la forma de detección de los latidos por minuto

## 3.4 Software en PC

En el caso de OXY_PULSE, no se utilizó ningún software que interactúe con el dispositivo desde la PC. Como posible mejora, podría buscarse una conexión con una interfaz gráfica por medio de un puerto serie para, por ejemplo, graficar las señales ECG y tener mejor precisión en la calibración del dispositivo.

## 3.4.1 Entorno de desarrollo

No corresponde.

## 3.4.2 Enumeración de rutinas

No corresponde.

## 3.4.3 Descripción del funcionamiento de cada rutina

No corresponde.

## 4 Modo de operación

El dispositivo cuenta con dos módulos, el gabinete principal y el clip para medición. Para realizar una medición, el usuario deberá seguir los pasos que se detallan a continuación:

1. En la parte superior del gabinete principal, se debe encender el dispositivo con la llave ON/OFF que se muestra en la figura 23. Previamente, se puede insertar una tarjeta microSD en la parte trasera del gabinete.

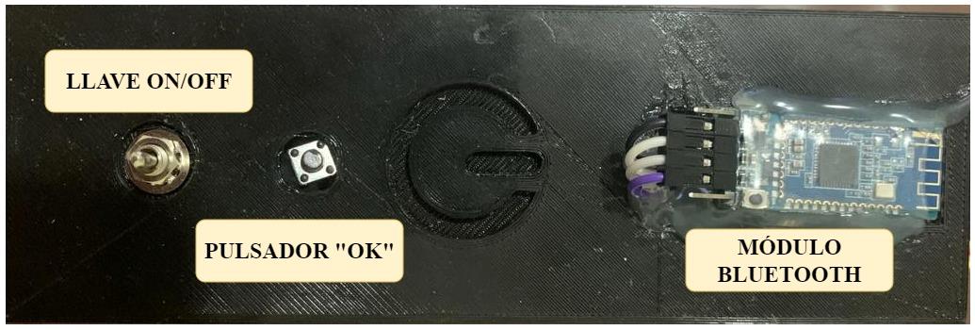
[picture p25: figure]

Figura 23 – Parte superior del gabinete principal

2. Una vez encendido el dispositivo, empezará la inicialización y se podrá observar la pantalla de inicio como en la figura 24. Además, a partir de ese momento se podrá vincular un dispositivo portátil con OXY_PULSE.

Figura 24 – Pantalla de inicialización

3. Al terminar la inicialización, se observará en pantalla la figura 25. La misma indica que OXY_PULSE está listo para realizar una medición.

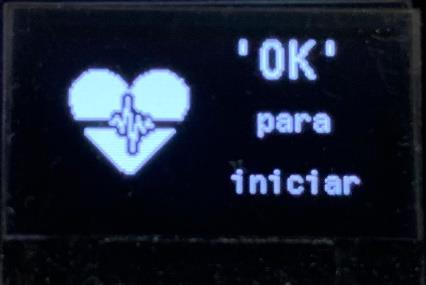
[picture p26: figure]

Figura 25 – Pantalla de espera para iniciar medición

4. Para comenzar con la medición se debe colocar el dedo en el clip para medición, teniendo en cuenta que deberá quedar sobre los leds del módulo oxímetro, y luego se acciona el pulsador “OK”.

5. Una vez pulsado “OK”, el dispositivo comenzará a mostrar valores de BPM (latidos por minuto) y SPO2 (saturación de oxígeno en sangre) como se muestra en la figura 26. Estos datos se irán transmitiendo al dispositivo móvil conectado vía Bluetooth y estarán siendo almacenados en un archivo de texto en la tarjeta microSD. Estos datos pueden ser útiles para generar un informe posterior del usuario al respecto.

Figura 26 – Pantalla de medición

6. Cuando se desee terminar la medición, se podrá pulsar “OK” nuevamente y se volverá a la pantalla de la figura 25.
7. Para comenzar una segunda medición el usuario debe entender que los valores guardados en la microSD se perderán al realizar una nueva medición.
8. Si el dispositivo se queda sin batería, se puede cargar conectando un cable microUSB en la parte inferior del gabinete gracias al módulo de carga, como se muestra en la figura 27. Cuando la batería llegue a plena carga, se encenderá un led azul del módulo indicando esto mismo.

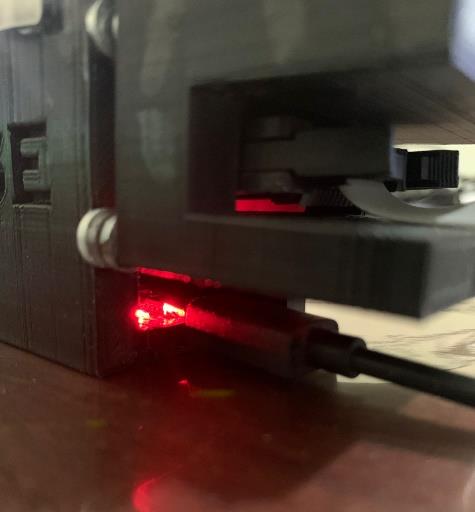
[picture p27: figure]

Figura 27 – Carga de OXY_PULSE

## 5 Ensayos

Como instrumento de medición relevante en el desarrollo, se utilizó un analizador lógico USB de 8 canales. Este dispositivo es un instrumento que captura los datos de un circuito digital para poder analizarlos, en forma similar a lo que hace un osciloscopio, y es capaz de visualizar señales de múltiples canales. Permite, además, la posibilidad de interpretar protocolos de comunicación como los que utiliza OXY_PULSE para vincular cada módulo (I2C, SPI, UART, etc.). En función de esto, se detallan algunas mediciones que fueron realizadas para el desarrollo de OXY_PULSE:

Comunicación I2C entre el microcontrolador y el MAX30100:
El módulo oxímetro MAX30100 implementa en su interior un registro FIFO para almacenar los datos obtenidos por el led rojo e infrarrojo. El mismo se organiza como un banco de memoria de 16 muestras, las cuales consisten en una palabra del led IR y una del led rojo, formando 4 bytes por cada muestra. Esto da como resultado un total de 64 bytes de datos que pueden ser almacenados en el registro FIFO. En la hoja de datos del módulo, se muestra la figura 28 donde se puede apreciar mejor la organización del registro.

Figura 28 – Representación gráfica de los datos del FIFO

En función de lo leído en la bibliografía detallada al final de este informe y siguiendo un pequeño pseudocódigo presente en la hoja de datos del módulo oxímetro, se realiza una lectura de una muestra leyendo 4 bytes del FIFO. El primer y segundo byte corresponden a los bits más significativos y menos significativos del led IR, respectivamente. Mientras que el tercer y cuarto byte corresponden a los bits más significativos del led rojo, respectivamente. Todas estas lecturas se realizan por el bus I2C, y se pueden observar en detalle gracias al uso de una herramienta como el analizador lógico. En figura 29, se observa la comunicación I2C, donde se puede apreciar el bit de START, una escritura del master con la dirección del esclavo (MAX30100), una escritura con la dirección del registro FIFO, una lectura de los 4 bytes seguidos correspondientes a los datos de cada led y finalmente un bit de STOP.

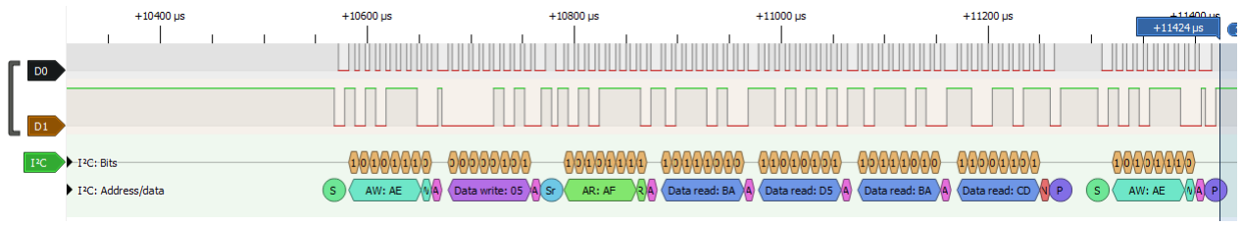
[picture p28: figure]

Figura 29 – Visualización del bus I2C en la lectura del FIFO

Esta lectura es el primer paso de la función “Actualizar_Resultados()” , exceptuando la de resetear la variable result. Esta función se debe implementar cada 27ms aproximadamente para que el filtrado funcione correctamente. Cuanto más se aproxime este intervalo de tiempo a 10ms (100Hz), mejor funcionará el filtrado según la bibliografía utilizada.

Comunicación SPI entre el microcontrolador y el módulo para tarjetas microSD
Otro uso que se le dio al analizador lógico fue para observar en detalle la comunicación SPI. Serial Peripheral Interface es un estándar de comunicación utilizado para realizar transferencias de información entre dispositivos electrónicos. Se trata de una comunicación sincrónica de 4 hilos, donde un dispositivo Master puede comunicarse con un dispositivo Slave (permite multi-slave). Posee señales de SCK (clock), CS (chip select), MOSI y MISO.
Cuando se fue a realizar la prueba de escritura en la tarjeta microSD por SPI, se presentó el problema de que el archivo .txt nunca era creado en la tarjeta. Utilizando el analizador lógico y con un debug paso a paso del código implementado, se identificó un problema en la función “LeerSector()”, la cual no era ejecutada correctamente. Esto se puede observar en la figura 30. El problema recaía en el largo del nombre del archivo, el cual excedía lo permitido por el FATFS implementado en el microcontrolador. Con un cambio en el largo del nombre del archivo por uno más corto, se realizó correctamente la escritura de datos en la microSD, obteniendo la captura de la figura 31.


Figura 30 – Visualización de la comunicación SPI errónea


Figura 31 – Visualización de la comunicación SPI correcta

Una vez que fueron corregidos los errores mencionados, se realizó una prueba completa del dispositivo y se guardaron los datos de una persona en la tarjeta micro SD. Dicha información fue utilizada para realizar el gráfico de la figura 32, del cual se puede observar que existe un tiempo de demora hasta que la lectura se estabiliza. Este tiempo puede relacionarse con aproximadamente 18 repeticiones del algoritmo implementado, por lo que, siendo prudentes se deben ignorar estos primeros valores, ya que no brindan información útil. Pasado este tiempo, se puede observar que la medición se mantiene relativamente estable, oscilando entre los 70 latidos por minuto.


Figura 32 – Gráfica de valores de latidos por minuto

Estos valores fueron comparados contra un oxímetro de pulso comercial, de la marca YONKER, modelo YK-81. Los valores de OXY_PULSE coincidieron con los del patrón utilizado, y esta prueba fue realizada por varios pacientes, verificando con éxito esto mismo.

## 6 Conclusiones

Con el diseño, pruebas y desarrollo de OXY_PULSE se obtuvieron los resultados y conclusiones que se detallan a continuación:

- La oximetría de pulsos es una prueba no invasiva para medir los latidos por minuto y la saturación de oxígeno en sangre y se utiliza muchas veces para monitorizar la salud de las personas con cualquier tipo de enfermedad que pueda afectar los niveles de oxígeno en sangre. Para ello, se requiere una lectura realmente precisa, ya que una mala información podría provocar un diagnóstico erróneo. La implementación del oxímetro con el módulo MAX30100 fue buena, pero no tan precisa como se esperaba. Las mediciones dependieron de la posición del dedo sobre el sensor, la presión del dedo sobre el sensor, que el clip esté perfectamente quieto y no se mueva, entre otras variables externas. Es por esto que sirve para tener una noción de los parámetros mencionados, pero no debe considerarse como una verdad absoluta bajo ningún concepto.
- Se realizó un desarrollo sobre una placa STM32, con un microcontrolador con arquitectura ARM, lo que permitió conocer en profundidad en qué consiste dicha arquitectura. Este punto es importante, dado que es una de las más utilizadas hoy en día para los dispositivos móviles como celulares, tablets, etc.
- Sobre el microcontrolador, se estudiaron los diferentes periféricos con los que cuenta, así como también la forma de configurarlo desde la interfaz .ioc en el software STM32CubeIDE. Se utilizaron buses I2C para comunicarse con el módulo MAX30100 y la pantalla OLED SSD1306, SPI para escribir datos en una tarjeta microSD y UART para transmitir datos utilizando un módulo bluetooth. Para esto, se estudiaron previamente dichos protocolos y cómo implementarlos con ejemplos sencillos.
- Para el montaje del proyecto, todas las partes mecánicas fueron diseñadas utilizando software CAD (Fusion 360), teniendo en cuenta las dimensiones de la placa, y todos los módulos que se buscaba utilizar. Y dichas partes fueron materializadas con una impresora 3D, la cual es una excelente opción para el prototipado rápido.
- El diseño del circuito impreso fue realizado con software libre KiCad, así como también el diseño del circuito esquemático donde figuran las conexiones realizadas en el proyecto.
- Se utilizó el analizador lógico de 8 canales como herramienta clave para la interpretación de protocolos de comunicación, y como ayuda para encontrar errores en el desarrollo.

En resumen, se desarrolló un proyecto que permitió entender mejor algunos conceptos sobre la programación de microcontroladores, así como también aprender nuevas técnicas, funciones, protocolos y demás herramientas útiles a la hora del desarrollo tecnológico.

## 7 Proyecto finalizado


Figura 33 – OXY_PULSE

## 8 Referencias

1. Diseño y construcción de un oxímetro de pulso – Autor: Solibella Bencomo, Sergio Villazana, Bruno Salas – Centro de Investigaciones en Bioingeniería, Universidad de Carabobo, Valencia, Venezuela.
2. Apunte Ley de Bouguer-Lambert-Beer – Universidad Veracruzana
3. Serie de Información al Paciente: Oximetría de pulso – American Thoracic Society
4. Implementing pulse oximeter using MAX30100 – Autor: Raivis Strogonovs
5. MAX30100 Datasheet - Maxim Integrated Products, Inc.
6. Description of STM32F1 HAL and low-layer drivers – STMicroelectronics
7. Apuntes teóricos de la catedra de Técnicas Digitales III.

Universidad Nacional de La Matanza Técnicas Digitales III

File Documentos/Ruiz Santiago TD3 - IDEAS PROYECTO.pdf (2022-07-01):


# IDEAS TD3 - PROYECTO

RUIZ SANTIAGO


## PROPUESTAS DE PROYECTOS


Oxímetro de Pulsos | Smart-Pills | Pañol inteligente

## OXIMETRO DE PULSOS


- Se trata de un prototipo de oxímetro de pulso capaz de medir los niveles de saturación de oxígeno en sangre y la frecuencia cardíaca.
- Presentará la información en una pantalla OLED con formato amigable para el usuario.
- Uso con baterías, por lo que será un dispositivo portátil.
- Posibilidad de comunicación bluetooth para enviar alertas al smartphone del usuario en caso de bradicardia (inferior a 60 latidos por minuto) y taquicardia (superior a 100 latidos por minuto).

## DIAGRAMA EN BLOQUES SIMPLIFICADO DEL PROYECTO


MÓDULO BLUETOOTH
HC-06


SENSOR DE PULSO
CARDÍACO Y
OXÍMETRO
MAX30102

BLUEPILL; RECIBIR ALERTAS; STM32F103

DISPLAY OLED
128*64


APP SENCILLA
PREPARADA PARA

## SMART-PILLS


- Se trata de un dispositivo capaz de dosificar la toma de una o varias medicaciones para un paciente con un determinado tratamiento.
- Se cargan las pastillas en su casillero vinculado al día correspondiente a ser tomadas. El dispositivo se encarga de que a una hora determinada del día en cuestión, las pastillas caigan y puedan ser consumidas por el paciente.
- Posibilidad de alertar al paciente vía Bluetooth en el horario y día correspondiente a la ingesta de la pastilla.
- Pantalla 16x2 con información útil para el usuario.

## DIAGRAMA EN BLOQUES SIMPLIFICADO DEL PROYECTO

BLUEPILL
STM32F103


MODULO RTC
DS3231


SERVOMOTOR
TOWER PRO SG90


LCD WINSTAR
16x2

MÓDULO BLUETOOTH
HC-06

APP SENCILLA
PREPARADA PARA
RECIBIR ALERTAS

## ORGANIZADOR DE HERRAMIENTAS INTELIGENTE


- Se trata de un almacenamiento inteligente, capaz de reconocer las herramientas disponibles, las que están siendo utilizadas y por quién está siendo utilizada.
- Cada empleado/usuario contará con una tarjeta magnética que lo identifica. Para tomar una herramienta, deberá registrarse con su tarjeta.
- Se podrán observar en pantalla las herramientas que están disponibles para ser usadas.
- El administrador posee una tarjeta “maestro”, que le permite obtener un informe del uso de las herramientas y si fueron o no devueltas.

## DIAGRAMA EN BLOQUES SIMPLIFICADO DEL PROYECTO


BLUEPILL
STM32F103


LCD WINSTAR
16x2


RFID RC522
MODULO LECTURA
DE TAGS


TAGS PARA
USUARIOS

SENSOR INFRARROJO
PARA CADA HERRAMIENTA

PULSADORES PARA EL MANEJO
DEL MENÚ

MODULO LECTURA/ESCRITURA SD OKY3001


## GRACIAS

SANTRUIZ@ALUMNO.UNLAM.EDU.AR

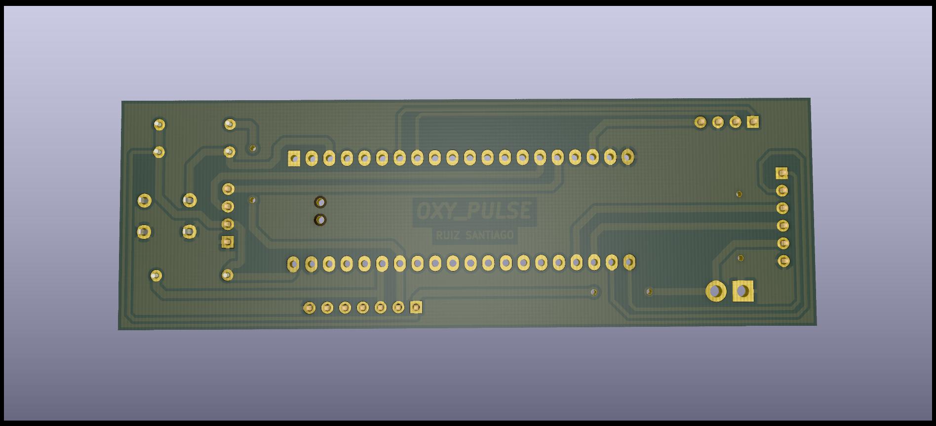
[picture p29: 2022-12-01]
Documentos/Esquematico_Oximetro_Pulsos/Oxy_Pulse_Back.jpg

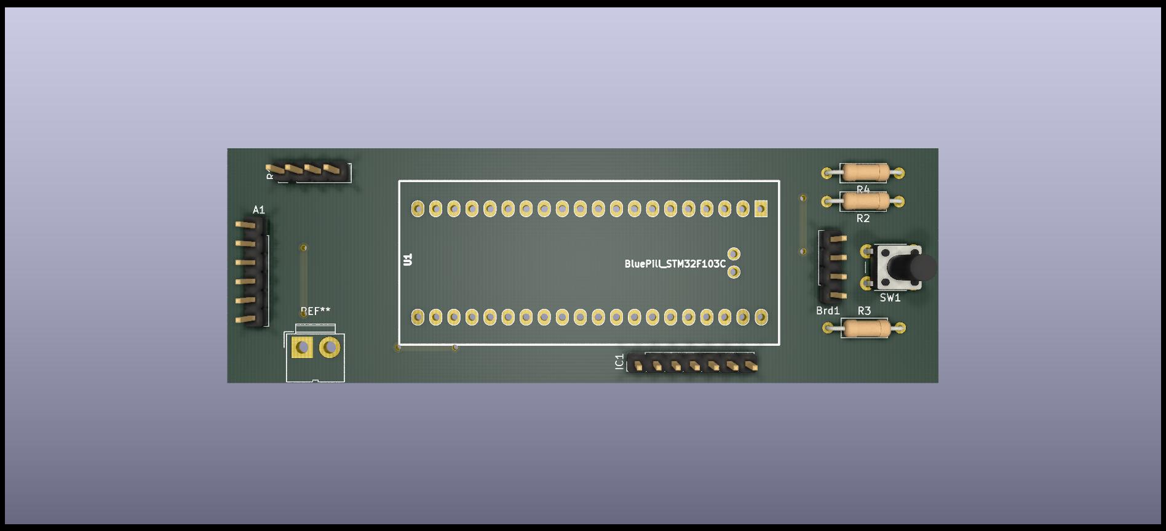
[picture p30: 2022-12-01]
Documentos/Esquematico_Oximetro_Pulsos/Oxy_Pulse_Frente.jpg

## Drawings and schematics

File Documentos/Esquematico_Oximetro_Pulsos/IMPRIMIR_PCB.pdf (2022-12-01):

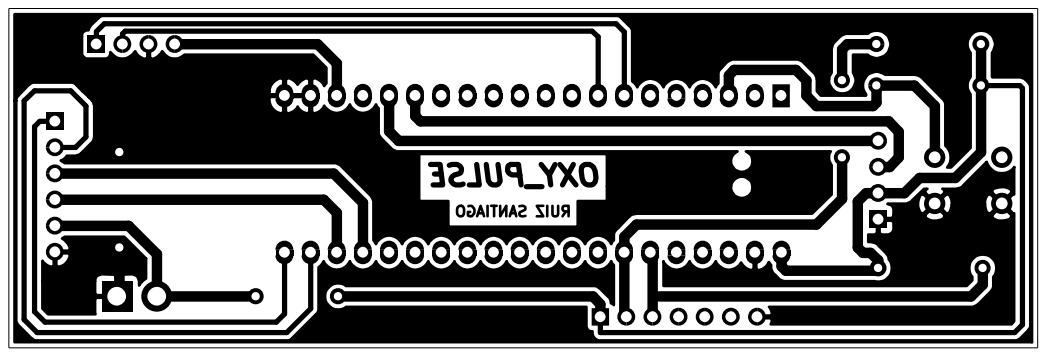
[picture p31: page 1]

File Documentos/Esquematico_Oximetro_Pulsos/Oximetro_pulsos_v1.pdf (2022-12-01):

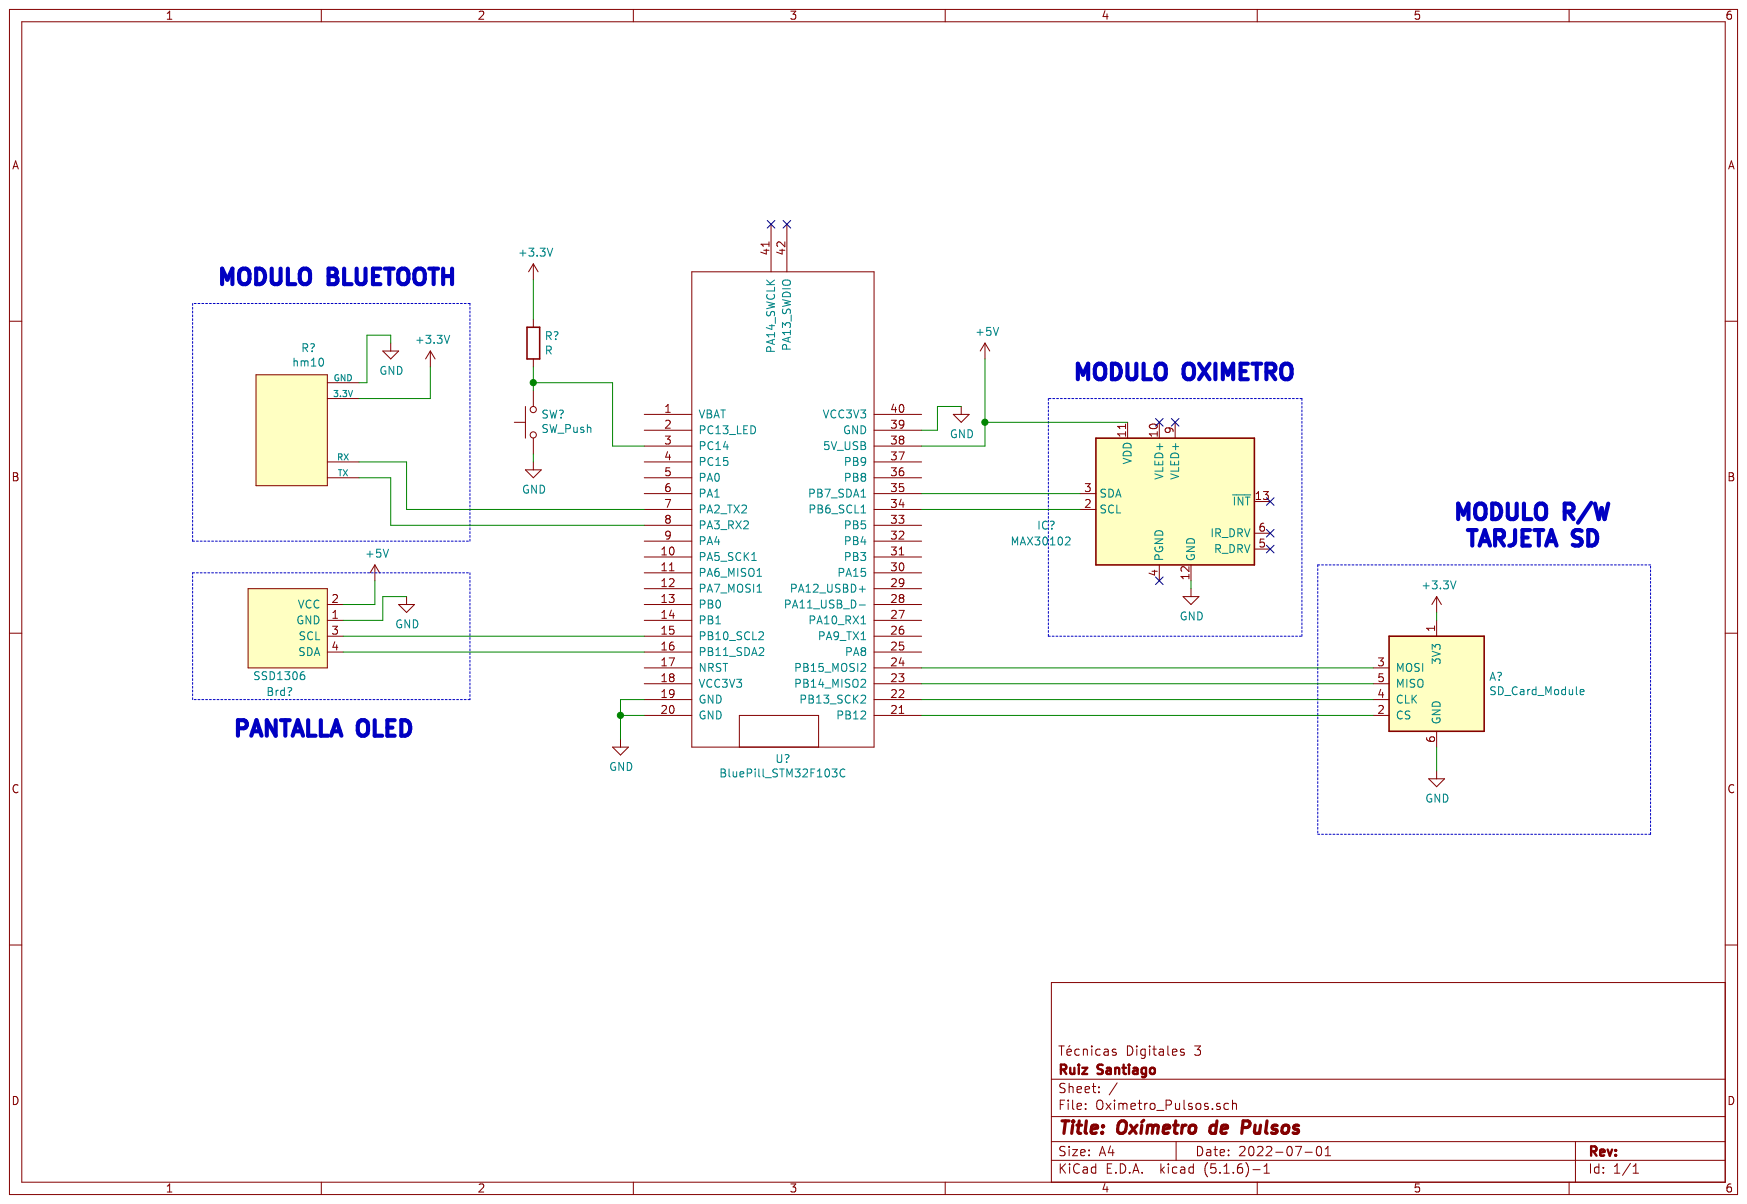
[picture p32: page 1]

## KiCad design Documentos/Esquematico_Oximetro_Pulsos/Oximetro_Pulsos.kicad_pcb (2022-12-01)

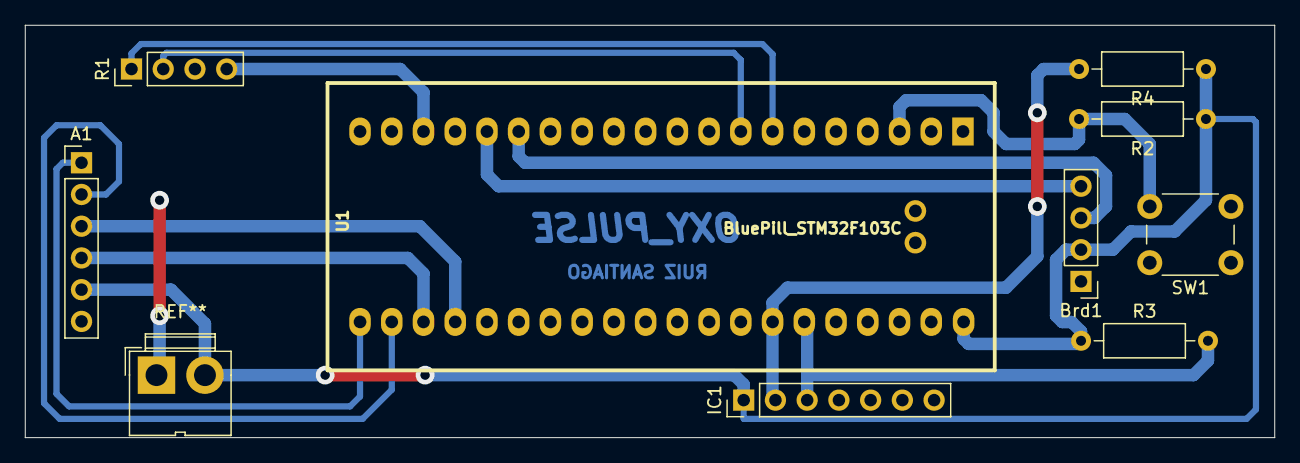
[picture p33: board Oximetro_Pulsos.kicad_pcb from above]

Board: 2 copper layers, 100.0 x 33.0 mm, 9 parts (0 on the bottom side), 13 nets.

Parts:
A1: SD_Card_Module; PinHeader_1x06_P2.54mm_Vertical
Brd1: SSD1306; PinHeader_1x04_P2.54mm_Vertical
IC1: MAX30102; PinHeader_1x07_P2.54mm_Vertical
R1: hm10; PinHeader_1x04_P2.54mm_Vertical
R2: R; R_Axial_DIN0207_L6.3mm_D2.5mm_P10.16mm_Horizontal
R3, R4: 4K7; R_Axial_DIN0207_L6.3mm_D2.5mm_P10.16mm_Horizontal
SW1: SW_Push; SW_PUSH_6mm_H13mm
U1: BluePill_STM32F103C

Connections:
+3V3: A1.5, Brd1.2, IC1.1, R1.4, R2.1, R3.1, R4.1, U1.18, U1.40
GND: A1.6, Brd1.1, IC1.7, R1.3, SW1.1, U1.19, U1.20, U1.39
unnamed: A1.1, U1.21
unnamed: A1.3, U1.24
unnamed: A1.2, U1.22
unnamed: A1.4, U1.23
unnamed: Brd1.3, U1.15
unnamed: Brd1.4, U1.16
unnamed: IC1.2, R4.2, U1.34
unnamed: IC1.3, R3.2, U1.35
unnamed: R1.2, U1.8
unnamed: R1.1, U1.7
unnamed: R2.2, SW1.2, U1.3

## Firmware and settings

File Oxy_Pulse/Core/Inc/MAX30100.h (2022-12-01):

/*
 * MAX30100.h
 *
 *  Created on: Aug 26, 2022
 *      Author: ssant
 */

#ifndef INC_MAX30100_H_
#define INC_MAX30100_H_

#define DEFAULT_OPERATING_MODE           	MAX30100_MODE_SPO2_HR

#define DEFAULT_SAMPLING_RATE				MAX30100_SAMPLING_RATE_100HZ
#define DEFAULT_LED_PULSE_WIDTH          	MAX30100_PULSE_WIDTH_1600US_ADC_16

#define DEFAULT_IR_LED_CURRENT           	MAX30100_LED_CURRENT_50MA
#define STARTING_RED_LED_CURRENT         	MAX30100_LED_CURRENT_27_1MA
//Ajustes para el balance de intensidades de RED LED
#define MAGIC_ACCEPTABLE_INTENSITY_DIFF    	65000
#define RED_LED_CURRENT_ADJUSTMENT_MS      	500

#define FIFO_WR_PTR_ADDRESS 			  	0x02


//SaO2
#define RESET_SPO2_EVERY_N_PULSES     		4

//Parámetros para el filtro DC
#define ALPHA 								0.95
#define MEAN_FILTER_SIZE        		  	15

//Parámetros para la detección del pulso
#define PULSE_MIN_THRESHOLD         		100 //probar con 300 si no funciona
#define PULSE_MAX_THRESHOLD         		2000
#define PULSE_GO_DOWN_THRESHOLD     		1

#define PULSE_BPM_SAMPLE_SIZE       		10 //tamaño del promedio móvil

#define MAX30100_DEVICE                   0x57

//Part ID Registers
#define MAX30100_REV_ID                   0xFE
#define MAX30100_PART_ID                  0xFF

//status registers
#define MAX30100_INT_STATUS               0x00
#define MAX30100_INT_ENABLE               0x01

//Fifo registers
#define MAX30100_FIFO_WRITE               0x02
#define MAX30100_FIFO_OVERFLOW_COUNTER    0x03
#define MAX30100_FIFO_READ                0x04
#define MAX30100_FIFO_DATA                0x05

//Config registers
#define MAX30100_MODE_CONF                0x06
#define MAX30100_SPO2_CONF                0x07
#define MAX30100_LED_CONF                 0x09

//Temperature registers
#define MAX30100_TEMP_INT                 0x16
#define MAX30100_TEMP_FRACTION            0x17

//Bit defines MODE Register
#define MAX30100_MODE_SHDN                (1<<7)
#define MAX30100_MODE_RESET               (1<<6)
#define MAX30100_MODE_TEMP_EN             (1<<3)
// Tipos de variables, structs y enums

typedef struct FIFO_t
{
	uint16_t rawIR;
	uint16_t rawRED;
} FIFO_t;

typedef struct pulseoxymeter_t
{
	bool 		pulseDetected;
	float 		heartBPM;
	float 		irCardiogram;
	float 		irDcValue;
	float 		redDcValue;
	float 		SaO2;
	uint32_t 	lastBeatThreshold;
	float 		dcFilteredIR;
	float 		dcFilteredRed;
} pulseoxymeter_t;

typedef struct meanDiffFilter_t
{
	float 		values[MEAN_FILTER_SIZE];
	uint8_t 	index;
	float 		sum;
	uint8_t 	count;
} meanDiffFilter_t;

typedef struct butterworthFilter_t
{
	float 		v[2];
	float 		result;
}butterworthFilter_t;

typedef struct dcFilter_t
{
	float 		w;
	float 		result;
}dcFilter_t;

typedef enum MODE {
    MAX30100_MODE_HR_ONLY                 = 0x02,
    MAX30100_MODE_SPO2_HR                 = 0x03
} MODE;

#define MAX30100_SPO2_HI_RES_EN           (1 << 6)

typedef enum SAMPLING_RATE {
    MAX30100_SAMPLING_RATE_50HZ           = 0x00,
    MAX30100_SAMPLING_RATE_100HZ          = 0x01,
    MAX30100_SAMPLING_RATE_167HZ          = 0x02,
    MAX30100_SAMPLING_RATE_200HZ          = 0x03,
    MAX30100_SAMPLING_RATE_400HZ          = 0x04,
    MAX30100_SAMPLING_RATE_600HZ          = 0x05,
    MAX30100_SAMPLING_RATE_800HZ          = 0x06,
    MAX30100_SAMPLING_RATE_1000HZ         = 0x07
} SAMPLING_RATE;

typedef enum LED_PULSE_WIDTH {
    MAX30100_PULSE_WIDTH_200US_ADC_13     = 0x00,
    MAX30100_PULSE_WIDTH_400US_ADC_14     = 0x01,
    MAX30100_PULSE_WIDTH_800US_ADC_15     = 0x02,
    MAX30100_PULSE_WIDTH_1600US_ADC_16    = 0x03,
} LED_PULSE_WIDTH;

typedef enum LED_CURRENT {
    MAX30100_LED_CURRENT_0MA              = 0x00,
    MAX30100_LED_CURRENT_4_4MA            = 0x01,
    MAX30100_LED_CURRENT_7_6MA            = 0x02,
    MAX30100_LED_CURRENT_11MA             = 0x03,
    MAX30100_LED_CURRENT_14_2MA           = 0x04,
    MAX30100_LED_CURRENT_17_4MA           = 0x05,
    MAX30100_LED_CURRENT_20_8MA           = 0x06,
    MAX30100_LED_CURRENT_24MA             = 0x07,
    MAX30100_LED_CURRENT_27_1MA           = 0x08,
    MAX30100_LED_CURRENT_30_6MA           = 0x09,
    MAX30100_LED_CURRENT_33_8MA           = 0x0A,
    MAX30100_LED_CURRENT_37MA             = 0x0B,
    MAX30100_LED_CURRENT_40_2MA           = 0x0C,
    MAX30100_LED_CURRENT_43_6MA           = 0x0D,
    MAX30100_LED_CURRENT_46_8MA           = 0x0E,
    MAX30100_LED_CURRENT_50MA             = 0x0F
} LED_CURRENT;

typedef enum Pulse_MEF{
	PULSE_IDLE							  =0X00,
	PULSE_TRACE_UP						  =0x01,
	PULSE_TRACE_DOWN					  =0x02
} Pulse_MEF;

extern FIFO_t *mainFIFO;

void MAX30100_Init(void);
void Inicio_Heart_Rate(void);
void Inicio_SPO2_HR(void);
void MAX30100_I2C_Reset_FIFO(void);
void MAX30100_I2C_Write(uint8_t, uint8_t, uint8_t);
void MAX30100_I2C_Read(uint8_t, uint8_t, uint8_t);
void MAX30100_I2C_FIFO_Read(uint8_t , uint8_t[]);
void Lectura_FIFO(FIFO_t *);
void Filtrado_DC(float,float*,float*);
void Mean_Median_Filter(float,meanDiffFilter_t*,float*);
void Filtro_PasabajosButterworth(float*,butterworthFilter_t*,float*);
bool detectPulse(float);
void Balance_Intensidades(float, float);
void Resetea_Resultados(pulseoxymeter_t *);
void SetHighresModeEnabled(void);
pulseoxymeter_t Actualizar_Resultados(void);
#endif /* INC_MAX30100_H_ */

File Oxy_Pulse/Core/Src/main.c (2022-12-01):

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
/* Includes ------------------------------------------------------------------*/
#include "main.h"
#include "fatfs.h"

/* USER CODE BEGIN Includes */
#include "stdio.h"
#include "stdbool.h"
#include "fonts.h"
#include "ssd1306.h"
#include "string.h"
#include "SPISD.h"
#include "Globals.h"
#include "MAX30100.h"
/* USER CODE END Includes */

/* USER CODE BEGIN PD */
#define DEMORA 4000
#define DEMORA2 1
#define DEMORA3 27
#define DEMORA4 5000
#define DEMORA5 10000
#define ACTIVADO 60
/* USER CODE END PD */

I2C_HandleTypeDef hi2c1;
I2C_HandleTypeDef hi2c2;

RTC_HandleTypeDef hrtc;

SPI_HandleTypeDef hspi2;

UART_HandleTypeDef huart2;

/* USER CODE BEGIN PV */

pulseoxymeter_t result;

SPISD spisd;
SPISD *mainSD = &spisd;
uint8_t Sector0[516];

uint16_t CONTADOR_1=DEMORA;
uint16_t CONTADOR_2=DEMORA2;
uint16_t CONTADOR_3=0;
uint16_t CONTADOR_4=0;
uint16_t CONTADOR_5=0;
uint16_t CONTADOR_ANTIRREBOTE=0;
uint16_t antirrebote=ACTIVADO;

uint8_t estado=0;
uint8_t state=0;
uint8_t byte;
uint8_t mensaje_START[]="Iniciando OXY_PULSE";
uint8_t mensaje_MIDIENDO[]="Listo para medir";
uint8_t mensaje_BPM[]="BPM:";
uint8_t mensaje_SPO2[]="SPO2:";
uint8_t mensaje_PULSO_PERDIDO[]="Pulso perdido...";
uint8_t mensaje_TAQUI[]="PELIGRO TAQUICARDIA";
uint8_t mensaje_BRADI[]="PELIGRO BRADICARDIA";

bool flag_pulso_perdido=0;
bool flag_pulsador_valido=0;
bool flag_estado_irq=1;
bool flag_HR_ON=0;
bool flag_limpiar=0;
bool flag_final=1;
bool flag_primera=1;
bool flag_mensaje=0;
bool flag_rebote=0;

bool debug=false;
const unsigned char LOGO [] = {
0x00, 0x00, 0x00, 0x00, 0x00, 0x00, 0x00, 0x00, 0x00, 0x00, 0x00, 0x00, 0x00, 0x00, 0x00, 0x00,
0x00, 0x00, 0x00, 0x00, 0x00, 0x00, 0x00, 0x00, 0x00, 0x00, 0x00, 0x00, 0x00, 0x00, 0x00, 0x00,
0x00, 0x00, 0x00, 0x00, 0x00, 0x00, 0x00, 0x00, 0x00, 0x00, 0x00, 0x00, 0x00, 0x00, 0x00, 0x00,
0x00, 0x00, 0x00, 0x00, 0x00, 0x00, 0x00, 0x00, 0x00, 0x00, 0x00, 0x00, 0x00, 0x00, 0x00, 0x00,
0x00, 0x00, 0x00, 0x00, 0x00, 0x00, 0x00, 0x00, 0x00, 0x00, 0x00, 0x00, 0x00, 0x00, 0x00, 0x00,
0x00, 0x00, 0x00, 0x00, 0x00, 0x00, 0x00, 0x00, 0x00, 0x00, 0x00, 0x00, 0x00, 0x00, 0x00, 0x00,
0x00, 0x00, 0x00, 0x00, 0x00, 0x00, 0x00, 0x00, 0x00, 0x00, 0x00, 0x00, 0x00, 0x00, 0x00, 0x00,
0x00, 0x00, 0x00, 0x00, 0x00, 0x00, 0x00, 0x00, 0x00, 0x00, 0x00, 0x00, 0x00, 0x00, 0x00, 0x00,
0x00, 0x00, 0x00, 0x00, 0x00, 0x00, 0x00, 0x00, 0x00, 0x00, 0x00, 0x00, 0x00, 0x00, 0x00, 0x00,
0x00, 0x00, 0x00, 0x00, 0x00, 0x00, 0x00, 0x00, 0x00, 0x00, 0x00, 0x00, 0x00, 0x00, 0x00, 0x00,
0x00, 0x00, 0x00, 0x00, 0x00, 0x00, 0x00, 0x00, 0x00, 0x00, 0x00, 0x00, 0x00, 0x00, 0x00, 0x00,
0x00, 0x00, 0x00, 0x00, 0x00, 0x00, 0x00, 0x00, 0x00, 0x00, 0x00, 0x00, 0x00, 0x00, 0x00, 0x00,
0x00, 0x00, 0x00, 0x00, 0x00, 0x00, 0x00, 0x00, 0x00, 0x00, 0x00, 0x00, 0x00, 0x00, 0x00, 0x00,
0x00, 0x00, 0x7F, 0x00, 0x00, 0xFE, 0x00, 0x00, 0x00, 0x00, 0x00, 0x00, 0x00, 0x00, 0x00, 0x00,
0x00, 0x01, 0xFF, 0xC0, 0x03, 0xFF, 0x80, 0x00, 0x00, 0x00, 0x00, 0x00, 0x00, 0x00, 0x00, 0x00,
0x00, 0x03, 0xFF, 0xF0, 0x0F, 0xFF, 0xC0, 0x00, 0x00, 0x00, 0x00, 0x00, 0x00, 0x00, 0x00, 0x00,
0x00, 0x07, 0xFF, 0xF8, 0x1F, 0xFF, 0xF0, 0x00, 0x00, 0x00, 0x00, 0x00, 0x00, 0x00, 0x00, 0x00,
0x00, 0x0F, 0xFF, 0xFC, 0x3F, 0xFF, 0xF0, 0x00, 0x00, 0x00, 0x00, 0x00, 0x00, 0x00, 0x00, 0x00,
0x00, 0x1F, 0xFF, 0xFE, 0x3F, 0xFF, 0xF8, 0x00, 0x00, 0x00, 0x00, 0x00, 0x00, 0x00, 0x00, 0x00,
0x00, 0x1F, 0xFF, 0xFE, 0x7F, 0xFF, 0xFC, 0x00, 0x00, 0x00, 0x00, 0x00, 0x00, 0x00, 0x00, 0x00,
0x00, 0x3F, 0xFF, 0xFF, 0xFF, 0xFF, 0xFC, 0x00, 0x00, 0x00, 0x00, 0x00, 0x00, 0x00, 0x00, 0x00,
0x00, 0x3F, 0xFF, 0xFC, 0x7F, 0xFF, 0xFC, 0x00, 0x00, 0x00, 0x00, 0x00, 0x00, 0x00, 0x00, 0x00,
0x00, 0x3F, 0xFF, 0xF8, 0x3F, 0xFF, 0xFC, 0x00, 0x00, 0x00, 0x00, 0x00, 0x00, 0x00, 0x00, 0x00,
0x00, 0x3F, 0xFF, 0xF9, 0x3F, 0xFF, 0xFC, 0x00, 0x00, 0x00, 0x00, 0x00, 0x00, 0x00, 0x00, 0x00,
0x00, 0x3F, 0xFF, 0xF9, 0x3F, 0xFF, 0xFC, 0x00, 0x00, 0x00, 0x00, 0x00, 0x00, 0x00, 0x00, 0x00,
0x00, 0x3F, 0xFF, 0xF9, 0x3F, 0xFF, 0xFC, 0x00, 0x00, 0x00, 0x00, 0x00, 0x00, 0x00, 0x00, 0x00,
0x00, 0x1F, 0xFF, 0xF9, 0x3F, 0xFF, 0xFC, 0x00, 0x00, 0x00, 0x00, 0x00, 0x00, 0x00, 0x00, 0x00,
0x00, 0x1F, 0xFF, 0xFB, 0x1F, 0xFF, 0xF8, 0x00, 0x00, 0x00, 0x00, 0x00, 0x00, 0x00, 0x00, 0x00,
0x00, 0x1F, 0xFF, 0xC3, 0x07, 0xFF, 0xF8, 0x00, 0x00, 0x00, 0x00, 0x00, 0x00, 0x00, 0x00, 0x00,
0x00, 0x0F, 0xFF, 0x83, 0x80, 0xFF, 0xF0, 0x00, 0x00, 0x00, 0x00, 0x00, 0x00, 0x00, 0x00, 0x00,
0x00, 0x0F, 0xFF, 0x92, 0x90, 0x7F, 0xF0, 0x00, 0x00, 0x00, 0x00, 0x00, 0x00, 0x00, 0x00, 0x00,
0x00, 0x00, 0x00, 0x3A, 0x91, 0x00, 0x00, 0x00, 0x00, 0x00, 0x00, 0x00, 0x00, 0x00, 0x00, 0x00,
0x00, 0x00, 0x00, 0x6E, 0x9B, 0x00, 0x00, 0x00, 0x00, 0x00, 0x00, 0x00, 0x00, 0x00, 0x00, 0x00,
0x00, 0x00, 0x00, 0x0C, 0xBB, 0x80, 0x00, 0x00, 0x00, 0x00, 0x00, 0x00, 0x00, 0x00, 0x00, 0x00,
0x00, 0x00, 0x00, 0x04, 0xAC, 0x00, 0x00, 0x00, 0x00, 0x00, 0x00, 0x00, 0x00, 0x00, 0x00, 0x00,
0x00, 0x00, 0xFF, 0xE4, 0xA4, 0x3F, 0x80, 0x00, 0x00, 0x00, 0x00, 0x00, 0x00, 0x00, 0x00, 0x00,
0x00, 0x00, 0xFF, 0xE0, 0xE0, 0xFF, 0x00, 0x00, 0x00, 0x00, 0x00, 0x00, 0x00, 0x00, 0x00, 0x00,
0x00, 0x00, 0x7F, 0xF0, 0xE1, 0xFE, 0x00, 0x00, 0x00, 0x00, 0x00, 0x00, 0x00, 0x00, 0x00, 0x00,
0x00, 0x00, 0x3F, 0xFE, 0x67, 0xFC, 0x00, 0x00, 0x00, 0x00, 0x00, 0x00, 0x00, 0x00, 0x00, 0x00,
0x00, 0x00, 0x1F, 0xFE, 0x47, 0xF8, 0x00, 0x00, 0x00, 0x00, 0x00, 0x00, 0x00, 0x00, 0x00, 0x00,
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
};

const unsigned char TILDE_OK [] = {
0x00, 0x00, 0x00, 0x00, 0x00, 0x00, 0x00, 0x00, 0x00, 0x00, 0x00, 0x00, 0x00, 0x00, 0x00, 0x00,
0x00, 0x00, 0x00, 0xC0, 0x00, 0x00, 0x00, 0x00, 0x00, 0x00, 0x00, 0x00, 0x00, 0x00, 0x00, 0x00,
0x00, 0x00, 0x03, 0x00, 0x00, 0x00, 0x00, 0x00, 0x00, 0x00, 0x00, 0x00, 0x00, 0x00, 0x00, 0x00,
0x00, 0x00, 0x0E, 0x00, 0x00, 0x00, 0x00, 0x00, 0x00, 0x00, 0x00, 0x00, 0x00, 0x00, 0x00, 0x00,
0x00, 0x00, 0x38, 0x00, 0x00, 0x00, 0x00, 0x00, 0x00, 0x00, 0x00, 0x00, 0x00, 0x00, 0x00, 0x00,
0x00, 0x00, 0x70, 0x00, 0x00, 0x00, 0x00, 0x00, 0x00, 0x00, 0x00, 0x00, 0x00, 0x00, 0x00, 0x00,
0x00, 0x03, 0xE0, 0x00, 0x00, 0x00, 0x00, 0x00, 0x00, 0x00, 0x00, 0x00, 0x00, 0x00, 0x00, 0x00,
0x0C, 0x07, 0xC0, 0x00, 0x00, 0x00, 0x00, 0x00, 0x00, 0x00, 0x00, 0x00, 0x00, 0x00, 0x00, 0x00,
0x07, 0x9F, 0x00, 0x00, 0x00, 0x00, 0x00, 0x00, 0x00, 0x00, 0x00, 0x00, 0x00, 0x00, 0x00, 0x00,
0x03, 0xFE, 0x00, 0x00, 0x00, 0x00, 0x00, 0x00, 0x00, 0x00, 0x00, 0x00, 0x00, 0x00, 0x00, 0x00,
0x00, 0xFC, 0x00, 0x00, 0x00, 0x00, 0x00, 0x00, 0x00, 0x00, 0x00, 0x00, 0x00, 0x00, 0x00, 0x00,
0x00, 0x7C, 0x00, 0x00, 0x00, 0x00, 0x00, 0x00, 0x00, 0x00, 0x00, 0x00, 0x00, 0x00, 0x00, 0x00,
0x00, 0x38, 0x00, 0x00, 0x00, 0x00, 0x00, 0x00, 0x00, 0x00, 0x00, 0x00, 0x00, 0x00, 0x00, 0x00,
0x00, 0x10, 0x00, 0x00, 0x00, 0x00, 0x00, 0x00, 0x00, 0x00, 0x00, 0x00, 0x00, 0x00, 0x00, 0x00,
0x00, 0x00, 0x00, 0x00, 0x00, 0x00, 0x00, 0x00, 0x00, 0x00, 0x00, 0x00, 0x00, 0x00, 0x00, 0x00,
0x00, 0x00, 0x00, 0x00, 0x00, 0x00, 0x00, 0x00, 0x00, 0x00, 0x00, 0x00, 0x00, 0x00, 0x00, 0x00,
0x00, 0x00, 0x00, 0x00, 0x00, 0x00, 0x00, 0x00, 0x00, 0x00, 0x00, 0x00, 0x00, 0x00, 0x00, 0x00,
0x00, 0x00, 0x00, 0x00, 0x00, 0x00, 0x00, 0x00, 0x00, 0x00, 0x00, 0x00, 0x00, 0x00, 0x00, 0x00,
0x00, 0x00, 0x00, 0x00, 0x00, 0x00, 0x00, 0x00, 0x00, 0x00, 0x00, 0x00, 0x00, 0x00, 0x00, 0x00,
0x00, 0x00, 0x00, 0x00, 0x00, 0x00, 0x00, 0x00, 0x00, 0x00, 0x00, 0x00, 0x00, 0x00, 0x00, 0x00,
0x00, 0x00, 0x00, 0x00, 0x00, 0x00, 0x00, 0x00, 0x00, 0x00, 0x00, 0x00, 0x00, 0x00, 0x00, 0x00,
0x00, 0x00, 0x00, 0x00, 0x00, 0x00, 0x00, 0x00, 0x00, 0x00, 0x00, 0x00, 0x00, 0x00, 0x00, 0x00,
0x00, 0x00, 0x00, 0x00, 0x00, 0x00, 0x00, 0x00, 0x00, 0x00, 0x00, 0x00, 0x00, 0x00, 0x00, 0x00,
0x00, 0x00, 0x00, 0x00, 0x00, 0x00, 0x00, 0x00, 0x00, 0x00, 0x00, 0x00, 0x00, 0x00, 0x00, 0x00,
0x00, 0x00, 0x00, 0x00, 0x00, 0x00, 0x00, 0x00, 0x00, 0x00, 0x00, 0x00, 0x00, 0x00, 0x00, 0x00,
0x00, 0x00, 0x00, 0x00, 0x00, 0x00, 0x00, 0x00, 0x00, 0x00, 0x00, 0x00, 0x00, 0x00, 0x00, 0x00,
0x00, 0x00, 0x00, 0x00, 0x00, 0x00, 0x00, 0x00, 0x00, 0x00, 0x00, 0x00, 0x00, 0x00, 0x00, 0x00,
0x00, 0x00, 0x00, 0x00, 0x00, 0x00, 0x00, 0x00, 0x00, 0x00, 0x00, 0x00, 0x00, 0x00, 0x00, 0x00,
0x00, 0x00, 0x00, 0x00, 0x00, 0x00, 0x00, 0x00, 0x00, 0x00, 0x00, 0x00, 0x00, 0x00, 0x00, 0x00,
0x00, 0x00, 0x00, 0x00, 0x00, 0x00, 0x00, 0x00, 0x00, 0x00, 0x00, 0x00, 0x00, 0x00, 0x00, 0x00,
0x00, 0x00, 0x00, 0x00, 0x00, 0x00, 0x00, 0x00, 0x00, 0x00, 0x00, 0x00, 0x00, 0x00, 0x00, 0x00,
0x00, 0x00, 0x00, 0x00, 0x00, 0x00, 0x00, 0x00, 0x00, 0x00, 0x00, 0x00, 0x00, 0x00, 0x00, 0x00,
0x00, 0x00, 0x00, 0x00, 0x00, 0x00, 0x00, 0x00, 0x00, 0x00, 0x00, 0x00, 0x00, 0x00, 0x00, 0x00,
0x00, 0x00, 0x00, 0x00, 0x00, 0x00, 0x00, 0x00, 0x00, 0x00, 0x00, 0x00, 0x00, 0x00, 0x00, 0x00,
0x00, 0x00, 0x00, 0x00, 0x00, 0x00, 0x00, 0x00, 0x00, 0x00, 0x00, 0x00, 0x00, 0x00, 0x00, 0x00,
0x00, 0x00, 0x00, 0x00, 0x00, 0x00, 0x00, 0x00, 0x00, 0x00, 0x00, 0x00, 0x00, 0x00, 0x00, 0x00,
0x00, 0x00, 0x00, 0x00, 0x00, 0x00, 0x00, 0x00, 0x00, 0x00, 0x00, 0x00, 0x00, 0x00, 0x00, 0x00,
0x00, 0x00, 0x00, 0x00, 0x00, 0x00, 0x00, 0x00, 0x00, 0x00, 0x00, 0x00, 0x00, 0x00, 0x00, 0x00,
0x00, 0x00, 0x00, 0x00, 0x00, 0x00, 0x00, 0x00, 0x00, 0x00, 0x00, 0x00, 0x00, 0x00, 0x00, 0x00,
0x00, 0x00, 0x00, 0x00, 0x00, 0x00, 0x00, 0x00, 0x00, 0x00, 0x00, 0x00, 0x00, 0x00, 0x00, 0x00,
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
};


uint8_t buf1=0;
uint8_t buf2=0;
uint8_t i=0;
uint16_t j=0;
char bufferserie_bpm[20];
char bufferserie_SPO2[20];
char bufferserie_bpm_SD[20];
char bufferserie_SPO2_SD[20];

char 	buffer_bpm[5]={0};
char 	buffer_SO2[5]={0};

typedef char 	datosSD[20];
datosSD			vectorSD[200];

float 	heartBPM_AVG=0;
float 	SaO2_AVG=0;

/* USER CODE END PV */

void SystemClock_Config(void);
static void MX_GPIO_Init(void);
static void MX_I2C1_Init(void);
static void MX_I2C2_Init(void);
static void MX_SPI2_Init(void);
static void MX_USART2_UART_Init(void);
static void MX_RTC_Init(void);
/* USER CODE BEGIN 0 */
RTC_HandleTypeDef *pRTC;
/* USER CODE END 0 */

/**
  * @brief  The application entry point.
  * @retval int
  */
int main(void)
{
  /* MCU Configuration--------------------------------------------------------*/

  /* Reset of all peripherals, Initializes the Flash interface and the Systick. */
  HAL_Init();

  /* Configure the system clock */
  SystemClock_Config();

  /* USER CODE BEGIN SysInit */
  spisd.FSM=Encendido;
  spisd.csPuerto = NSS_GPIO_Port;
  spisd.csPin = NSS_Pin;
  spisd.puertoSPI = &hspi2;
  spisd.sectorAddressing=1; //Asumimos SDHC (+2GB)
  spisd.hrtc = &hrtc;
  pRTC=&hrtc;
  /* USER CODE END SysInit */

  /* Initialize all configured peripherals */
  MX_GPIO_Init();
  MX_I2C1_Init();
  MX_I2C2_Init();
  MX_SPI2_Init();
  MX_USART2_UART_Init();
  MX_RTC_Init();
  MX_FATFS_Init();
  /* USER CODE BEGIN 2 */
  SSD1306_Init();
  MAX30100_Init();
  HAL_UART_Receive_IT(&huart2, &byte, sizeof(byte));

  SSD1306_GotoXY(95, 2);
  SSD1306_Puts("v1.1",&Font_7x10,1);
  SSD1306_GotoXY(40, 0);
  SSD1306_Puts("OXY",&Font_16x26,1);
  SSD1306_GotoXY(25, 24);
  SSD1306_Puts("PULSE",&Font_16x26,1);
  SSD1306_GotoXY(10, 50);
  SSD1306_Puts("...Iniciando...",&Font_7x10,1);
  SSD1306_UpdateScreen();
  SSD1306_ScrollRight(0x06, 0x07);



  f_mount(&USERFatFS,USERPath,0);
  f_open(&USERFile,"OXY.txt",FA_CREATE_ALWAYS | FA_WRITE);
  uint32_t output;
  f_write(&USERFile,"VALORES:\n",strlen("VALORES:\n"),(void*)&output);
  f_sync(&USERFile);

   //   f_write(&USERFile,"\nOXY_PULSE",sizeof("OXY_PULSE"),(void*)&output);
   //   f_write(&USERFile,"\nOXY_PULSE",sizeof("OXY_PULSE"),(void*)&output);
   //   f_write(&USERFile,"\nOXY_PULSE",sizeof("OXY_PULSE"),(void*)&output);
   //   f_write(&USERFile,"\nOXY_PULSE",sizeof("OXY_PULSE"),(void*)&output);
   //if (f_write(&USERFile,"OXY_PULSE",sizeof("OXY_PULSE"),(void*)&output)==FR_OK)
//   {
 	//  if (f_sync(&USERFile)==FR_OK){
 		//  f_close(&USERFile);
 	  //}

   //}
   //Inicio_SPO2_HR();
   //Inicio_SPO2_HR();

  /* USER CODE END 2 */

  /* Infinite loop */
  /* USER CODE BEGIN WHILE */
  while (1)
  {
    /* USER CODE END WHILE */

    /* USER CODE BEGIN 3 */
	  switch(estado){
	  case INICIANDO:
	  	  //PANTALLA 1: INICIANDO EL DISPOSITIVO
/////////////////////////////////////////////////////////////////////////////

		  if(!CONTADOR_1)
		  {
			  estado=PREPARADO;
			  CONTADOR_1=DEMORA;
			  SSD1306_Stopscroll();
			  SSD1306_Clear();

			  HAL_UART_Transmit(&huart2, mensaje_START, sizeof(mensaje_START), HAL_MAX_DELAY);
		  }
		  ///////////////////////////////////////////////////////////////////
		  break;
	  case PREPARADO:
		  	  //PANTALLA 2: PULSAR PARA COMENZAR LA MEDICIÓN
/////////////////////////////////////////////////////////////////////////////
		  SSD1306_DrawBitmap(0, 0, LOGO, 128, 64, 1);
		  SSD1306_GotoXY(70, 0);
		  SSD1306_Puts("'OK'",&Font_11x18,1);
		  SSD1306_GotoXY(80, 27);
		  SSD1306_Puts("para",&Font_7x10,1);
		  SSD1306_GotoXY(70, 50);
		  SSD1306_Puts("iniciar",&Font_7x10,1);
		  SSD1306_UpdateScreen();
////////////////////////////////////////////////////////////////////////////


		  if(!CONTADOR_1 && flag_pulsador_valido)
		  {
			estado=MIDIENDO;							//SE ESPERA QUE SE ACCIONE EL PULSADOR. CUANDO SE PULSA, FLAG_PULSADOR=1
			MAX30100_I2C_Reset_FIFO();				//SE RESETEA EL FIFO Y SE LIMPIA LA VARIABLE RESULT
			CONTADOR_3=DEMORA4;						//CAMBIO AL SIGUIENTE ESTADO "MIDIENDO"
			Resetea_Resultados(&result);
			flag_limpiar=1;
			flag_primera=1;
			flag_pulsador_valido=0;


		  }

		  if(flag_limpiar)
		  {
			  SSD1306_Clear();							//FLAG PARA LIMPIAR CORRECTAMENTE LA PANTALLA Y EVITAR PARPADEOS
			  flag_limpiar=0;
		  }

		  if(CONTADOR_1 && !flag_pulsador_valido && !flag_mensaje)
		  {
			  HAL_UART_Transmit(&huart2, mensaje_MIDIENDO, sizeof(mensaje_MIDIENDO), HAL_MAX_DELAY);
			  HAL_UART_Receive_IT(&huart2, &byte, sizeof(byte));
			  flag_mensaje=1;
		  }
		  break;
		  	  	  	  	  	 	 	 	 	 	 	 	 //TRANSMISIÓN BLUETOOTH mensaje_START "Iniciando OXY_PULSE.."

	  case MIDIENDO:

		  result=Actualizar_Resultados();				//ACTUALIZACIÓN DE LA VARIABLE "result" IMPLEMENTANDO EL ALGORITMO EN MAX30100.c

		  estado=PRESENTACION;							//CAMBIO DE ESTADO AL SIGUIENTE CASE PARA PRESENTAR VALORES EN PANTALLA
		  CONTADOR_1=DEMORA3; 							//DEMORA DE 27ms PARA LA CORRECTA EJECUCION DEL FILTRADO

		  //CONTADOR_3=DEMORA4;

		  if(flag_primera && !flag_limpiar)
		  {
			  flag_rebote=0;
			  flag_limpiar=1;							//LA PRIMERA VEZ QUE SE PASA POR EL CASE "MIDIENDO" DEBO LIMPIAR LA PANTALLA
			  flag_primera=0;							//EN FUTUROS PASOS FLAG_PRIMERA=0
			  CONTADOR_2=DEMORA;						//DEMORA PARA LIMPIAR PANTALLA
		  }
			//  antirrebote=ACTIVADO;
		  break;
	  case PRESENTACION:

		  if(flag_limpiar && !flag_primera)								//LIMPIO PANTALLA SOLO LA PRIMERA VEZ
		  {
			SSD1306_Clear();
			flag_limpiar=1;
			flag_primera=1;
			i=0;
		  }

		  if(result.pulseDetected == true)
		  {
				  flag_pulso_perdido=0;
				  CONTADOR_4=0;
				  buf1=(uint8_t)result.heartBPM;
				  buf2=(uint8_t)result.SaO2;

				  if(buf2>99)
				  {
					  buf2=99;				//PARA NO MOSTRAR PORCENTAJES MAYORES A 99%
				  }

				  sprintf(bufferserie_bpm,"%s %u \n",mensaje_BPM,(unsigned)buf1);
				  sprintf(bufferserie_SPO2,"%s %u \n",mensaje_SPO2,(unsigned)buf2);
				  //sprintf(bufferserie_bpm,"%s %u \n",mensaje_BPM,(unsigned)result.heartBPM);
				  //sprintf(bufferserie_SPO2,"%s %u \n",mensaje_SPO2,(unsigned)result.SaO2);

				  sprintf(buffer_bpm,"%u",buf1);
				  sprintf(buffer_SO2,"%u",buf2);

				  HAL_UART_Transmit(&huart2, (uint8_t*)bufferserie_bpm, strlen(bufferserie_bpm), HAL_MAX_DELAY);
				  HAL_UART_Transmit(&huart2, (uint8_t*)bufferserie_SPO2, strlen(bufferserie_SPO2), HAL_MAX_DELAY);

				  strcpy(vectorSD[j],bufferserie_bpm);
				  j++;
				  strcpy(vectorSD[j],bufferserie_SPO2);
				  j++;
				  /*
				  f_write(&USERFile,bufferserie_bpm,strlen(bufferserie_bpm),(void*)&output);
				  f_write(&USERFile,bufferserie_SPO2,strlen(bufferserie_SPO2),(void*)&output);
				  f_sync(&USERFile);
				  */
				  if(!flag_limpiar && buf1<100)
				  {
					  SSD1306_Clear();
					  flag_limpiar=1;
				  }

				  SSD1306_GotoXY(10, 5);
				  SSD1306_Puts("BPM:",&Font_11x18,1);
				  SSD1306_GotoXY(70, 5);
				  SSD1306_Puts(buffer_bpm,&Font_11x18,1);
				  //SSD1306_Putc(buf1, &Font_11x18, 1);
				  SSD1306_GotoXY(10, 35);
				  SSD1306_Puts("SO2:",&Font_11x18,1);
				  SSD1306_GotoXY(70, 35);
				  SSD1306_Puts(buffer_SO2,&Font_11x18,1);
				  //SSD1306_Putc(buf2, &Font_11x18, 1);
				  SSD1306_GotoXY(90, 35);
				  SSD1306_Puts(" %",&Font_11x18,1);
				  SSD1306_UpdateScreen();

				  if(flag_limpiar && buf1>100)
				  {
					  flag_limpiar=0;
				  }
			  }

			  if(!CONTADOR_1 && !flag_pulsador_valido)
			  {
				  estado=MIDIENDO;
				  CONTADOR_1=0;
			  }

		  	  if(flag_pulsador_valido)
		  	  {
		  		  estado=PREPARADO;
		  		  flag_limpiar=1;
		  		  flag_primera=1;
		  		  flag_pulsador_valido=0;
		  		  for(int k=0;k<j;k++)
		  		  {
					  f_write(&USERFile,vectorSD[k],strlen(vectorSD[k]),(void*)&output);
		  		  }
		  		  f_sync(&USERFile);
		  		  f_close(&USERFile);
		  	  }


///////////////////////////////////////////////////
			//LIMPIO PANTALLA CADA 10ms
			 /* if(!CONTADOR_2)
			  {
				  CONTADOR_2=DEMORA;
				  SSD1306_Clear();
			  }
			  */
//////////////////////////////////////////////////
	/*		  if(!result.pulseDetected)
			  {
				  switch(state)
				  {
				  case 0:

						  CONTADOR_4=DEMORA4;
						  state=1;
						  flag_pulso_perdido=1;

					  break;

				  case 1:
					  if (!CONTADOR_4 && flag_pulso_perdido)
					  {
						  //SSD1306_Clear();
						  buf1=0;
						  buf2=0;
						  sprintf(buffer_bpm,"%u",buf1);
						  sprintf(buffer_SO2,"%u",buf2);
						  SSD1306_GotoXY(10, 5);
						  SSD1306_Puts("BPM:00",&Font_11x18,1);
						  //SSD1306_GotoXY(70, 5);
						  //SSD1306_Puts(buffer_bpm,&Font_11x18,1);

						  SSD1306_GotoXY(10, 35);
						  SSD1306_Puts("SO2:00",&Font_11x18,1);
						  //SSD1306_GotoXY(70, 35);
						  //SSD1306_Puts(buffer_SO2,&Font_11x18,1);

						  SSD1306_GotoXY(90, 35);
						  SSD1306_Puts(" %",&Font_11x18,1);
						  SSD1306_UpdateScreen();
						  CONTADOR_4=0;
						  state=0;

						  HAL_UART_Transmit(&huart2, mensaje_PULSO_PERDIDO, sizeof(mensaje_PULSO_PERDIDO), HAL_MAX_DELAY);
					  }
					  break;
				  default:;
				  }
			  }
*/

		  break;
	  	  default:;
		  }
  }



  /* USER CODE END 3 */
}

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
/* USER CODE BEGIN 4 */
//*************************************************************
//Función: 			HAL_IncTick
//Descripción: 		Manejo del Systick para demoras en ms
//Parámetros: 		void
//Valor devuelto: 	void
//*************************************************************

void HAL_IncTick(void)
{
  uwTick += uwTickFreq;

  if(CONTADOR_1)
	  CONTADOR_1--;

  if(CONTADOR_2)
	  CONTADOR_2--;

  if(CONTADOR_3)
	  CONTADOR_3--;

  if(CONTADOR_4)
	  CONTADOR_4--;

  if(CONTADOR_ANTIRREBOTE)
	  CONTADOR_ANTIRREBOTE--;

  if(!CONTADOR_ANTIRREBOTE && HAL_GPIO_ReadPin(GPIOC, GPIO_PIN_14)==0 && !flag_estado_irq)
  {
	  flag_pulsador_valido=1;
	  CONTADOR_ANTIRREBOTE=0;
	  flag_estado_irq=1;
  }
}

void HAL_UART_RxCpltCallback(UART_HandleTypeDef *huart)
{
	/*	HAL_UART_Transmit(&huart2, &byte, sizeof(byte), 100);

		//HAL_UART_Receive(&huart2, &byte, sizeof(byte), HAL_MAX_DELAY);
		if (byte == '0')
			HAL_GPIO_WritePin(LED_GPIO_Port, LED_Pin, 0);

		if (byte == '1')
			HAL_GPIO_WritePin(LED_GPIO_Port, LED_Pin, 1);
*/
	//Habilito la interrupción
	HAL_UART_Receive_IT(&huart2, &byte, sizeof(byte));
}

void HAL_UART_TxCpltCallback(UART_HandleTypeDef *huart)
{
	//HAL_UART_Transmit(&huart2, &buf1, sizeof(buf1), HAL_MAX_DELAY);
	HAL_UART_Receive_IT(&huart2, &byte, sizeof(byte));
}

//*************************************************************
//Función: 			HAL_GPIO_EXTI_Callback
//Descripción: 		Manejo de la interrucpción externa
//Parámetros: 		uint16_t GPIO_Pin
//Valor devuelto: 	void
//*************************************************************
void HAL_GPIO_EXTI_Callback(uint16_t GPIO_Pin)
{
	if(flag_estado_irq)
	{

		flag_estado_irq=0;
		CONTADOR_ANTIRREBOTE=50;
	}
}


int Promedio_Movil(int *ptrArrNumbers,long*ptrSum,int pos, int len, int nextNum)
{
	  //Subtract the oldest number from the prev sum, add the new number
	  *ptrSum = *ptrSum - ptrArrNumbers[pos] + nextNum;
	  //Assign the nextNum to the position in the array
	  ptrArrNumbers[pos] = nextNum;
	  //return the average
	  return *ptrSum / len;
}
/* USER CODE END 4 */
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


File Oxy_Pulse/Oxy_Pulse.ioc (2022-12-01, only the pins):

Mcu.UserName=STM32F103C8Tx
PA13.Signal=SYS_JTMS-SWDIO
PA14.Signal=SYS_JTCK-SWCLK
PA2.Signal=USART2_TX
PA3.Signal=USART2_RX
PB10.Signal=I2C2_SCL
PB11.Signal=I2C2_SDA
PB12.GPIO_Label=NSS
PB12.Signal=GPIO_Output
PB13.Signal=SPI2_SCK
PB14.Signal=SPI2_MISO
PB15.Signal=SPI2_MOSI
PB6.Signal=I2C1_SCL
PB7.Signal=I2C1_SDA
PC13-TAMPER-RTC.GPIO_Label=LED
PC13-TAMPER-RTC.Signal=GPIO_Output
PC14-OSC32_IN.Signal=GPXTI14
PD0-OSC_IN.Signal=RCC_OSC_IN
PD1-OSC_OUT.Signal=RCC_OSC_OUT

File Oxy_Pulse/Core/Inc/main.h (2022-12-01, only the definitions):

#define LED_Pin GPIO_PIN_13
#define LED_GPIO_Port GPIOC
#define NSS_Pin GPIO_PIN_12
#define NSS_GPIO_Port GPIOB
#define INICIANDO 		0
#define PREPARADO 		1
#define MIDIENDO 		2
#define PRESENTACION 	3

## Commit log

2022-07-01 Agregado del archivo de ideas de proyecto
2022-07-28 Primer commit del proyecto. Configuraciones del IOC para habilitar UART,I2C y SPI.
2022-07-28 Agregado de CSS y formato del README.
2022-07-28 Corrección de README
2022-08-09 Agregado de la función del Bluetooth y algunas librerías para el MAX30100.
2022-09-26 Programación de funciones en MAX30100 No mide correctamente, pero se reciben valores del sensor y se realiza el procesamiento. En busca de errores.
    [MAX30100.c, MAX30100.h, Oxy_Pulse.ioc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]
2022-10-15 Correccion en lectura de FIFO Falta agregar promediado de valores de BPM y SPO2
2022-11-18 Integracion de modulos, no funciona la SD
2022-12-01 Código estable con mediciones correctas de BPM y SPO2
    [MAX30100.c, MAX30100.h, Oxy_Pulse.ioc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]
2022-12-01 Agregado de documentación, imagenes e informes.
    [IDC_PCB.kicad_pcb, IDC_PCB.sch, Oximetro_Pulsos.kicad_pcb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]
2022-12-01 Agregado de imagenes en el README

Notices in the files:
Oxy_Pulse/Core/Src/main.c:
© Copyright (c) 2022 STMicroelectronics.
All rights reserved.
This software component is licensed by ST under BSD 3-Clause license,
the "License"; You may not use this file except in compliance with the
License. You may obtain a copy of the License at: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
